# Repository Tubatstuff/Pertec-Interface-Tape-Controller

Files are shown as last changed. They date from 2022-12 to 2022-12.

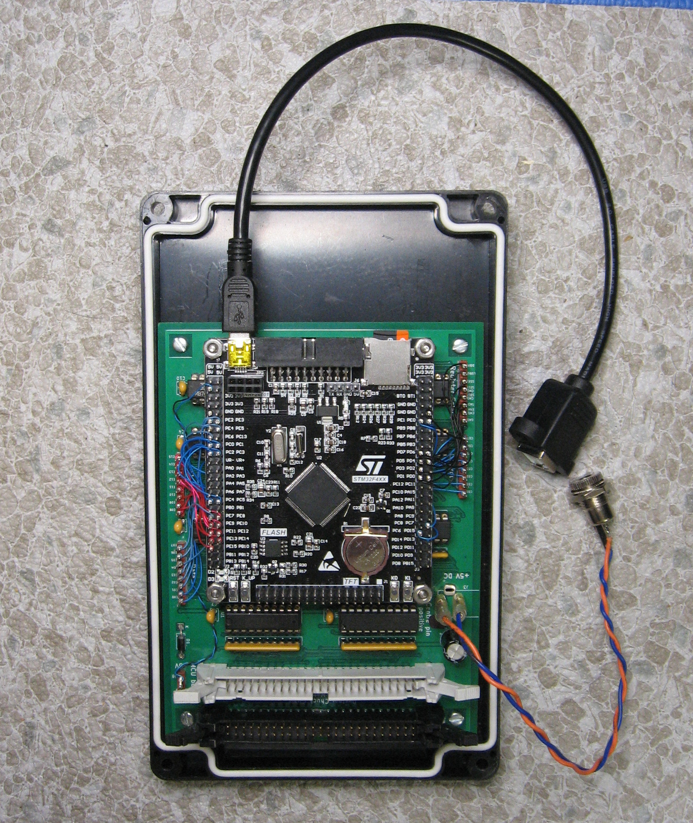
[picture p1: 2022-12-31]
doc/Pertec_Assem.jpg

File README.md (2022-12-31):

This is the repository for a controller to formatted Pertec tape interface.

The directories are as follows:

	doc - Documentation
	firmware - Controller firmware
	kicad - KiCAD schematics, board layout, etc.

The firmware can be built from source using the gcc-arm-none-eabi compiler
and the libopencm3 development library (libopencm3.org) which is covered by
the GNU General Public License v3.0, as is this project.

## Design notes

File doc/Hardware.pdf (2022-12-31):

# Pertec Tape Controller, Version 1.0

January, 2023
Chuck Guzis, Sydex, Inc.

FOREWORD

This document describes the operation of my Pertec tape drive controller. This controller consists of the Pertec bus interface logic and an STM32F4 microcontroller, although any microcontroller of sufficient capabilities can be used.
Frequent reference is made to the Pertec interface description, located in the file 'Pertec 9-Track Tape Interface.pdf'. The library used for the microcontroller program is located at https://libopencm3.org/. The microcontroller data sheets can be found at http://www.st.com.

INTERFACE CONVENTIONS

The Pertec interface is typical for its time; 5 volt TTL, with transmitting done via open-collector logic terminated in 220 ohm to +5, 330 ohm to ground resistor networks. Logic is negative; that is, 0 volts is true, 5 volts is false.
There are about 52 unidirectional signal lines that are distributed over two 50-conductor cables with interleaved ground lines. Depending on vendor implementation, some of these signals may not be used. Others may have vendor-unique interpretations.
Unlike many protocols, the Pertec protocol does not involve handshaking. Data read is transferred from the tape formatter and marked by pulsing a strobe line true--there is no corresponding controller-to-formatter protocol signalling that the data has been accepted. Similarly, when writing, whatever data is present on the controller-to-formatter data lines is transferred to tape and the transfer marked by pulsing a "data written" strobe.
Various other signals may be pulsed during the read or write process; it is up to the controller to "catch" these signals.
Commands to the tape formatter involve data transfer or tape motion without data transfer. For data transfer (i.e. read and write), operations are initiated by the controller pulsing the "IGO" line; that is, bringing the level low for at 2 microseconds. Operation commences on the trailing edge of the pulse and "formatter busy" is asserted. The type of operation is determined by other command lines.
For example, a simple read in the forward direction involves pulsing IGO with no other lines asserted. As each byte is presented to the controller, the IRSTR line is pulsed. A read in the reverse direction involves asserting IREV with IGO.
Writing is initiated by asserting IWRT with IGO. As the formatter acceptseach byte of data from the controller, IWSTR is pulsed. However, see below for the use of ILWD (last word) to signal the end of a block.

All data transfer operations involve the formatter setting IDBY active for the duration of the transfer, after which IFBY is also de-asserted.
Non-data transfer, i.e. tape motion, operations do not set IDBY, but do set IFBY (formatter busy) and do not involve IGO. So, to rewind a tape to load point, IRWD is pulsed, IREW goes active, with IRDY (drive ready) going inactive. When load point is reached, IREW goes inactive and IRDY goes active.
Similarly, if IRWU is pulsed (some implementations require that IREW also be asserted), the tape rewinds and is unloaded and is ready for removal.
Block length is signaled on a read by IDBY going inactive during a read operation. On writing, ILWD must be asserted just before presenting the last byte of data in a block. Generally, ILWD can be asserted immediately after IWSTR goes inactive for the penultimate byte in a block.
Errors are signaled during a transfer; there are two general types. ICER is pulsed for a "corrected" error during reading. IHER is pulsed for a "hard" (uncorrected) error during both read and write operations. IFMK is pulsed during a read when a file mark (tape mark) is encountered.
There are other operations that can be implemented by a given drive/formatter combination; many of these are vendor-unique and are discussed in the documentation for your particular drive.

CONTROLLER IMPLEMENTATION

The controller as implemented here consists of two main parts. The first part is simply TTL level logic to interface to the tape formatter and consists mostly of flip-flops, receivers and random logic. The purpose is to reduce the 52 signal lines down to fewer I/O lines and to catch any pulses emitted by the formatter. The second part is a microcontroller that represents the "brains" of the controller.

INTERFACE LOGIC

Please refer to the schematic for this narrative.

TAPE DRIVE CONNECTORS (Sheet 2)

All signal lines are shown. Only 2 are unconnected; ISGL which, on some drives signals 800 bpi NRZ mode; and IDENT, which indicates that the drive is reading the identification burst information. Neither controls drive operation and either does not appear on many drive implementations.
IFEN is strapped as permanently active. The use of multiple separate formatters on drives shared by multiple hosts is not common on current systems.
All other formatter-to-controller signals are terminated by 220/330 ohmresistor networks RN1, RN2 and RN3.

TAPE CONTROL REGISTERS (Sheet 3)

U10 and U11 are 74ABT574 8 bit latches that are capable of driving 60 ma loads. Other families’ version of this latch may be used, provided that a 40 ma drive capability is ensured. They are connected to 16 control bits on the formatter interface. At startup, they are both tri-stated (high impedance), and enabled by bringing the CMDENA line low from the microcontroller. The upper or lower 8 bits of the 16 output signals are clocked from the microcontroller via the CMDSEL0 and CMDSEL1 lines. Since the latches are in high-impedance mode at startup, they cannot affect drive operation even if they are loaded with random values. As usual, these lines are low-active.
N.B. It is possible to reduce the number of GPIO bits required by connecting the command data lines to the MCU data in/out lines and loading either half of the control registers from the data lines. Logic will be a bit more complicated, however.

TAPE DATA REGISTERS AND DATA CONTROL (Sheet 4)

Data in and out to the formatter is latched by U1 and U2 (74ABT574). Both are connected to the microcontroller which must operate the common lines bidirectionally. The data direction (read or write) is controlled by the DDIR signal from the microcontroller, which tri-state enables one or the other (OE is driven through inverter U3A). In the case of output during a write operation, odd parity is generated by U5, 74LS280. Many drives do not use this signal, but it's provided for completeness.
Read and write strobes (IRSTR and IWSTR) are caught on the trailing edge by flip-flops (74LS74) U4A and U4B. The output of these is incorporated in the status registers (see section 3.1.5, Sheet 6).
Both registers are reset by the microcontroller pulsing TACK low.
Note that the output register U2 must be latched with data before IGO and IWRT are asserted. Thereafter, WDEMTPY is asserted after each byte is accepted by the formatter. Prior to the last byte to be written is latched into U2, ILWD must be asserted.
For reading, RDAVAIL is set when the formatter makes a byte of read data available.

POWER/MICROCONTROLLER INTERFACE (Sheet 5)

Sheet 5 describes the headers dedicated to the microcontroller interface. These are wired to appropriate pins on the microcontroller card.
+5 volts is provided from two sources; the first is the external connection via J3; the second is supplied via the microcontroller card, which is, in turn supplied by the USB interface. Schottky diode D1 prevents external power coming in via J3 from over-driving the USB power.
Bypass capacitors (104) are supplied at every IC.

STATUS REGISTERS (Sheet 6)

Tri-state buffers U6 and U7 furnish status information from the formatter as well as the transient status for file mark, corrected error and hard error, latched by U8 and U9. These 3 status bits ar reset at the trailing edge of the IGO signal, as all three statuses occur during data transfer.
Output from U6 and U7 is selected by the SSEL microcontroller signal. The status bits are arranged such that the status selection need not be changed during the data phase of a read or write
command. U6 and U7 may be any TTL-compatible logic family (e.g. LS, AS, HCT, ACT, etc.) but must not be CMOS (e.g. HC) because the signal levels at the 220/330 termination from the tape drive result in high level signals that are specified as “ambiguous” for 5 volt CMOS. The result could be erratic operation of failure of U6 or U7.

MICROCONTROLLER OPERATION OUTLINE

The code required to run the Pertec interface is straightforward. The basic tasks are as follows:
1. Initialize clocks, GPIO, tape interface, SD card interface and USB communication interface.
2. Poll for next operation to be performed.
3. Perform the operation; go to step 2.

INITIALIZATION

On microcontroller powerup, all GPIO ports should be in input mode with weak pullup enabled. This prevents any undesired activity on the tape drive.

The interface is organized as several 8-bit ports, set up as follows:
1. Data port (J4), bidirectional, initially in input mode.
2. Status port (J5), input mode.
3. Control port (J6), output mode
4. Register select port (J7), output mode
On some microcontrollers, particularly ARM-based ones, GPIO ports are generally 16 bits. Writing a value to an 8 bit half of a 16-bit register is a bit unconventional. One first sets all bits in the 8 bit half to ones, then clears the appropriate bits that are desired to be zeroes.
The register select (J7) port should be first initialized with all high-level bits (ones). This has the effect of disabling the control port output.
Next, the control port (J6) should be written with all ones in both 8 bit halves, using the register select bits (CMDSEL0 and CMDSEL1) set appropriately.

Register select bit TACK should be pulsed to reset the data status bits.

SD card, communications and clock should be set up as appropriate for the choice of microcontroller and software.

TAPE POSITIONING

Tape can be rewound, unloaded, or spaced in the forward direction by first ensuring that the tape drive is online and ready. This is done by polling for the IRDY bit active. If a rewind is attempted, it can be skipped if the ILDP (load point) status is active.
The appropriate command bits are set in the control port using the register select (CMDSEL0 and CMDSEL1) bits. Before setting, the control port output should be disabled (CMDENA bit), the control register loaded, then enabled.
Operation status should be monitored until complete.

TAPE READING

Tape reading operation is similar to the tape positioning protocol, with the difference that IGO is pulsed at the beginning of the operation. Further, TACK should also be pulsed to clear the "read data available" flag. All error flags are reset upon release of IGO. Tape motion ensues, with IFBY being set. When data has been processed by the formatter, IDBY goes active and each byte read setting the RDAVAIL flag in the status register. The data byte can then be read from the data register and stored. The transfer is then acknowledged by pulsing TACK. At the conclusion of the tape block transfer, IDBY is released. On many streaming drives, it is not necessary to wait for IFBY to clear; the next command can be issued immediately. Error flags and file mark indication are available in status register.
Most tape formatters read an entire block, process it, then transfer it to the host. As a consequence, transfers occur in bursts, with idle time between. This should leave more than enough time to write the block to the SD card; in our implementation on the STM32F407, the data write to SD is initiated using DMA transfer, such that SD writing can overlap with tape reading.

TAPE WRITING

Tape writing is initiated in a manner similar to tape reading, with several important differences. The data register is set to output mode; output data is latched into the data register before the write operation is initiated. Upon data being transferred to the tape drive, the WDEMPTY bit is set in the status register and the next data byte should be latched into the data register. Before the last byte of a block is written, the ILWD bit should be set in the control register. This can be done as soon as the WDEMPTY bit is set for the preceding byte. Note that the IFPT (file protect) bit will be set in the status register if the tape has not been write-enabled (no "ring").
Tape marks are written by asserting IWRT and IWFM as well as IGO. This will result in a single file mark being written. The IEOT status should be tested before each block write to avoid writing past end-of-tape.

MISCELLANEOUS NOTES

A few implementation-specific details should be noted here.

The FAT32 file system implemented on the SD card, is realized using Elm Chan's FATFS. Single file size is limited to 2GB, which should not be a problem, even at 6250 GCR density.
Our implementation time- and date-stamps each file as it is created. This is done by virtue of the microprocessor card used containing a clock backup battery.
By default, tape image files are recorded in SIMH TAP format.

The source code contains provisions for host interface via USB CDC ACM or, alternatively, serial asynchronous I/O at 115200 bps. The selection is done by specifying a compile-time option. Transfer from SD card to host can be done in two ways. The SD card can be removed and inserted into a suitable SD reader on the host system. As an alternative, YMODEM 1K transfer is implemented. Many terminal programs, such as Linux minicom support this protocol.
A few ICs, the 74LS04 and 74LS74 ICs have unused, unterminated inputs. These should be tied to +5 or 0 volts if CMOS HCT logic is used. On the current version of the PCB, this should be done manually; currently, they are left open for the possibility of future modification.

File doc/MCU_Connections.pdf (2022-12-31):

# Connections Between PTCB and STM32F4VExx MCU Module

## January, 2023

C. P. Guzis, Sydex, Inc.

As described in the “Hardware” document, the prototype Pertec Tape Controller board was implemented using the STM32F4VEXX development board described here: https://stm32-base.org/boards/STM32F407VET6-STM32-F4VE-V2.0.html.
The connections from the controller board to the MCU were made using wire-wrap techniques, but a cable using Dupont connectors should probably be the preferred method. Another possibility is to construct a “mezzanine” printed circuit board that plugs into the controller board and mates with the microcontroller development board of choice.
In any case, the software supplied with the board uses the following pin assignments. In all cases, the first reference is to the controller board pin, the second is the microcontroller connection:
J8:
+5 → any 5V
GND → any GND
Data:
E00 → PE0 E02 → PE2 E04 → PE4 E06 → PE6 E01 → PE1 E03 → PE3 E05 → PE5 E07 → PE7 Status:
E08 → PE8 E10 → PE10 E12 → PE12 E14 → PE14 E09 → PE9 E11 → PE11 E13 → PE13 E15 → PE15 Control:
C00 → PC0 C02 → PC2 C04 → PC4 C06 → PC6 C01 → PC1 C03 → PC3 C05 → PC5 C07 → PC7
Register Select:
CMD ENA → PD1 DDIR → PD5 | LDBUF → PD4 | SSEL → PD3
CMD SEL0 → PD7 CMD SEL1 → PD6 TACK → PD0 | GND → any GND

Note that it’s possible to change any of these association by editing the gpiodef.h file. All other uses of the pin names in the software are symbolically referenced.

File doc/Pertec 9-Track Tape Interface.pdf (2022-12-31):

# Pertec 9-Track Tape Interface

## Electrical

The interface uses two 50 conductor (ribbon) cables, P1 and P2. All odd-numbered conductors are grounded, with the exception of conductors 1 and 3 on P2.

All signal levels are TTL (5 volt). Drivers are open-collector and must be capable of sinking 36 mA. The last device on each end of any cable should be terminated on all receive lines with 220 ohms to +5 volts and 330 ohms to ground. (Note: I suspect that 220 ohm to 1K ohm to +5 will suffice on short (less than 1 meter cable runs.)

All signals are active-low.

## Signal Definitions

In the following, the source (driver) of the signal is signified by either Drive for the tape drive or Host for the host (controller). Note also, that the bit ordering is IBM-style. That is, bit 0 is the most significant bit in a byte and bit 7 is the least significant bit position. Don't let this trip you up!

P1 Connections

P1 Pin | Signal Name | Asserted by | Description
2 | IFBY | Drive | Forrmatter busy—Set by trailing edge of IGO, clears when command finished (but you can send a new command as soon as IDBY clears)
4 | ILWD | Host | Last word—Used to tell drive that this is the last word (byte) to be written in this record, Must be asserted at least 300 nsec. before trailing edge of final IWSTR pulse.
6 | IW4 | Host | Write data bit 4
8 | IGO | Host | Initiate command—Pulsed low for at least 1µsec. to start command execution. The formatter address lines must be stable throughout the pulse and until IFBY drops.
10 | IW0 | Host | Write data bit 0 (MSB!)
12 | IW1 | Host | Write data bit 1
14 | ISGL | Drive | Selected drive fault on some drives; NC on others. If used, it is cleared by de-asserting, then re-asserting IFEN.
16 | ILOL | Host | Load on-line—Pulsing this line at least 1µsec. begins the tape load sequence on many drives.
18 | IREV | Host | Reverse—When asserted, indicates operation is to be performed in the reverse direction.
20 | IREW | Host | Rewind—A pulse of at least 1 µn;sec. starts the tape rewind sequence. Completion is signalled by IRWD going inactive and IRDY being asserted by the drive.

22 | IWP | Host | Write parity. This is (almost always) odd parity computed over IW0–IW7 and on some drives is ignored and computed by the formatter.
24 | IW7 | Host | Write data bit 7 (LSB!)
26 | IW3 | Host | Write data bit 3
28 | IW6 | Host | Write data bit 6
30 | IW2 | Host | Write data bit 2
32 | IW5 | Host | Write data bit 5
34 | IWRT | Host | Write—When asserted with IGO begins a write sequence.
36 | IRTH2 | Host | Write density select 2—On some drives, this signal, along with IRTH1 is used to select the drive write density. If it is implemented, it is valid only at BOT and must be asserted with IGO during the first write sequence.
38 | IEDIT | Host | Edit—Not implmented on all drives. See notes in the next section for details on its application.
40 | IERASE | Host | Erase—When asserted with IWRT and IGO, causes tape to be erased, usually for a predetermined length. Usually used to recover from write errors or provide extra space for mode changes (i.e. Read after write).
42 | IWFM | Host | Write filemark&mash;When asserted with IWRT, writes a filemark.
44 | IRTH1 | Host | Write density control—See IRTH2, pin 36.
46 | ITAD0 | Host | Transport address bit 0 (MSB!)—Used to address multiple drives on a single controller.
48 | IR2 | Drive | Read data bit 2
50 | IR3 | Drive | Read data bit 3
All odd | Gnd | – | Signal ground.

P2 Connections

P2 Pin | Signal Name | Asserted by | Description
1 | IRP | Drive | Read data parity (odd) This is not a ground pin!
2 | IR0 | Drive | Read data bit 0 (MSB!)
3 | IR1 | Drive | Read data bit 1 This is not a ground pin!
4 | ILDP | Drive | Load point—Asserted whenever the tape is at the load point (or might as well be, as far as the controller needs to know -- there may be hidden repositioning)
6 | IR4 | Drive | Read data bit 4

8 | IR7 | Drive | Read data bit 7 (LSB!)
10 | IR6 | Drive | Read data bit 6
12 | IHER | Drive | Hard error—Pulsed during IDBY when a hard data error (or illegal character in the IRG) is seen. Note that most modern formatters correct this error automatically.
14 | IFMK | Drive | File mark—Pulsed during IDBY when a tape mark is seen. Note that you have to catch this as it goes by!
16 | IDENT | Drive | Identification—Asserted while drive is actually reading the PE ID burst, dropped the rest of the time so it's up to the controller to catch it and remember.
18 | IFEN | Host | Formatter enable—This signal should normally be asserted all the time. If dropped for a minimum of 2 µsec., aborts any comman that asserts IDBY (I/O, skip, but not rewind or unload).
20 | IR5 | Drive | Read data bit 5
22 | IEOT | Drive | End of tape—Asserted whenever the tape is past the EOT marker, clears when the tape is backspaced past it.
24 | IRWU | Host | Rewind and unload—A pulse of at least 1 µsec. initiates a rewind-with-unload and sets drive off-line. Some drives require that IREW is also asserted.
26 | INRZ | Drive | NRZI mode—Signals 800 BPI mode on some drives.
28 | IRDY | Drive | Ready—Signals that tape is fully loaded, on-line and not rewinding. This must be asserted by the drive before it will accept any command.
30 | IRWD | Drive | Rewinding—This is asserted by the drive while the tape is rewinding.
32 | IFPT | Drive | File protect—This signal is asserted continuously when the tape is not write-enabled (i.e. no ring present).
34 | IRSTR | Drive | Read strobe—Pulses low for at least 200 nsec. when data on IR0-IR7 and IRP are stable before leading edge; typically held for 200 nsec., but this is not a requirement. Note that data is made available–there is no check made to ensure that the host has picked it up.
36 | IWSTR | Drive | Write strobe—Pulses low for at least 200 nsec. when the drive is ready to accept data. This is roughly similar to an "Acknowledge" signal after data has been received. The next data byte can be presented immediately.
38 | IDBY | Drive | Data busy—This signal is asserted during I/O phase of read or write commands. It generally lags a few milliseconds after the drive asserts IFBY.
40 | ISPEED | Drive | High-speed—This signal is asserted when commands are executing in high-speed mode; that is, when the drive is not operating in start-stop mode.
42 | ICER | Drive | Corrected error—This signal is pulsed during IDBY when a single-track dropout is successfully corrected using the parity information.

44 | IONL | Drive | Online—Asserted when the drive is online; clears within 1 µsec. of being taken offline.
46 | ITAD1 | Host | Transport address bit 1 (LSB!)
48 | IFAD | Host | Formatter address
50 | IHISP | Host | High speed select—When asserted 1 µsec. before and then with IGO (de-asserted any time after the trailing edge of IGO selects high-speed (streaming) mode.
5-49 odd | Gnd | – | Signal ground.

## Usage

Commands are started by setting up the IREV, IWRT, IWFM, IEDIT, and IERASE signals and then pulsing IGO. Various combinations of these signals are possible to get vendor-specific commands.

The basic ones are:

Read

Assert IGO. The drive reads data and presents data at IR0–IR7, strobing each byte with IRSTR. No check is made for data received by the host; it's simply shoveled out by the drive until the end-of-block or error. ICER and IHER signal soft and hard errors, respectively and IFMK will indicate a filemark. Observe that these signals are just pulses that accompany each data byte—they do not latch.

Read Reverse

Assert IGO while asserting IREV. Operates the same as a forward read, but data is presented in reverse order.

Write

Assert IWRT while asserting IGO. As the formatter accepts each byte of data, it signals with the IWSTR strobe. Again, no check is made to see if the data presented at IW0-IW7 and IWP is valid--the host must present data and parity prior to the assertion by the drive of IWSTR. When the last byte in a block is presented for writing, the host must assert ILWD.

Write Filemark

Assert IWRT and IWFM while asserting IGO. One filemark will be written.

Erase

Assert IWRT, IWFM and IERASE while asserting IGO. This command erases a few inches of tape, usually as part of a write error recovery sequence.

Skip Block Forward

Assert IERASE with IGO. This functions similarly to a read but with no data transfer.

Skip Block Reverse

Assert IERASE and IREV with IGO. This is similar to a read reverse operation, but with no data transfer.

Search Filemark Forward

Assert IWFM and IERASE with IGO. This causes the drive to skip forward to the next filemark or EOT. The tape is left positioned after the filemark

Search Filemark Reverse

Assert IWFM, IREV and IERASE with IGO. This causes the drive to skip backward to the preceding filemark or BOT. The tape is left positioned before the filemark

Miscellany

On some drives, IEDIT modifies reverse reads and forward writes so that a record can be replaced. Asserting IEDIT while doing a reverse read causes the drive to move further back into the IRG preceding the record being spaced over. Asserting IEDIT while writing tells the drive to modify the write current turn-off to avoid a glitch.

Streamers have a drive-dependent "reinstruct time" which is the size of the time window after completion of a command during which you can issue a new command without the drive having to reposition. If you fail to make this window, then the drive stops and backspaces a few records to get a running start at the next record. This can waste a lot of time and movement. Asserting IHISP needlessly will probably result in operations taking longer if succeeding operations cannot be issued in time, so care must be used in attempting to use the "high speed" mode of operation.

As regards transfer speeds, a good rule of thumb is that an interface should be designed to provide or receive data at least at 1MB/second. Observe that there's no handshaking for data transfers, so it's incumbent on the controller to satisfy all timing requirements.

Glossary

Here are a few terms used in this discussion:

BOT or "beginning of tape". This is not the physical start of a tape, but rather the point after the beginning where a reflective foil tape marker has been applied. All tape before this is classified as "leader".

EOT or "end of tape". This is not the physical end of the tape, but rather a point somewhere before the physical end where a reflective foil marker has been placed. As a rule of thumb, it's safe to write at least one short record past the EOT marker.

Filemark is a reserved bit pattern used to delimit files on a tape. Most drives can scan a tape in either forward or reverse directions at high speed to locate a filemark. Some system software uses two or three consecutive filemarks to provide extra levels of delineation.

Write enable or "write ring" is a plastic ring that fits into a groove in the back of a reel of tape to tell the drive that it's safe to write to the tape. "No ring, no write" is an old data processing rule.

Formatter is a intermediate interface between the drive and the controller that provides buffering and error correction facilities for a drive or group of drives. One formatter can service several drives. It's also possible to interface a drive to more than one formatter.

Parity is used for error control on tape drives. One bit in a nine-bit frame is reserved for parity and some tape formats also append a longitudinal parity frame at the end of a block, so that single errors can be corrected. In 9-track tapes, the number of bits in a frame must be odd. Some 7 track tape formats allowed for even parity as long as no all-zero frames are written.

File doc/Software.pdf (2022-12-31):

# A Guide to the Pertec Tape Controller Software

## January, 2023

Chuck Guzis, Sydex Inc.

## Introduction

This document serves as a guide to implementing microcontroller (“MCU”) firmware for the Pertec Tape Controller board (“PTCB”). This should not be construed as a strict set of rules, but merely guidelines, should a different microcontroller or firmware be desired.

As written, the firmware supplied was targeted at a specific MCU board, the STM32F4xx development board employing an ST Micro STM32F407 microprocessor. It was selected primarily because it was inexpensive, had more than adequate speed and memory and 5 volt tolerant GPIO, support for SD cards and full-speed USB OTG. It also has provisions for an Ethernet MAC and other features not used. A battery-backed real-time clock/calendar was a plus for time-stamping files.

Since the PTCB employs TTL-level logic, an MCU with 5 volt tolerant I/O is important, unless the implementer desires to add external level-shifting logic. It should be noted that the MCU is not directly connected to any of the tape interface pins, so drive/current sinking requirements are minimal.

As designed, the software allows for use of either asynchronous serial (UART) or USB (CDC ACM) interfaces, the choice being determined at compilation time.

## Requirements

An essential understanding of the interface to the PTCB logic is important when selecting an MCU. Note should be taken of the following:

There are 4 8-bit GPIO interfaces on board:

One 8 bit bidirectional interface for data.

One 8 bit output interface for drive control.

One 8 bit input interface for status.

One 8 bit output interface for logic control.

Data interfaces employ latches to hold data going to and from the drive. The drive formatter itself has no handshake provisions; it signals when a byte is available for reading and when it has accepted a byte for writing. Flip-flops record the state of both types of traffic and can be interrogated in the status register.
Some signals are transient during a data transfer, such as hard error status; they too, are made available in the status register.

Since an 8 bit interface to all registers is used, the logic control lines signal which latch is being addressed by the MCU. For example, there are 16 status signals, divided into two groups of 8 bits; the first are signals that should be interrogated during a data transfer; the second are static signals that can be checked after a transfer has been concluded.

If GPIO is at a premium, it should be possible to make use of only three 8-bit GPIO interfaces, with the drive control sharing the data interface. This has not be tried, but there appears to be no impediment toward using the interface in this way.

The logic control interface determines which 8 bit status register is selected for reading by the MCU, which 8 bit drive control register is selected, and the state of the data registers (empty or full). Additionally, a signal is provided to force the drive control registers into a high-impedance state.

For a call-out of the various tape interface signals, see the interface description in the PTCB hardware description document.

Status Registers
The status registers are configured thus; note that the status as read is negative logic (0 level = true):

Status register 0:

xxxx xxx1 = Read data parity bit; not used by most drives, which enforce odd parity.

xxxx xx1x = Data busy; corresponds to the IDBY interface signal.

xxxx x1xx = High speed mode; corresponds to the IHSP interface signal, used on streaming drives.

xxxx 1xxx = Read data available; signals that data has been latched; cleared by asserting TACK.

xxx1 xxxx = Write data buffer empty; signals that the drive has accepted data; cleared by TACK.

xx1x xxxx = File mark detected; cleared by asserting the GO control signal.

x1xx xxxx = Hard (uncorrectable) error detected; cleared by GO assertion.

1xxx xxxx = Corrected error detected; cleared by GO assertion.

Status register 1:

xxxx xxx1 = IRNZ; used by some drives to signal 800 bpi mode.

xxxx xx1x = End of tape detected; corresponds to IEOT on the tape interface.

xxxx x1xx = Drive is online; corresponds to IONL on the tape interface.

xxxx 1xxx = File protect; corresponds to IFPT on the tape interface.

xxx1 xxxx = Tape is rewinding; corresponds to IRWD on the tape interface.

xx1x xxxx = Tape is at load point (beginning); corresponds to ILDP on the tape interface.

x1xx xxxx = Drive is loaded and ready; corresponds to IRDY on the tape interface.

1xxx xxxx = Formatter busy; corresponds to IFBY on the tape interface.

Command Registers
The two command registers are negative-logic and configured thus:

Command register 0:

xxxx xxx1 = “GO” – when asserted, initiates data activity on trailing edge Also resets error status.

xxxx xx1x = Last word. Used during writes, must be asserted before the last byte is transferred

xxxx x1xx = Load; on some drives, pulsing this line initiates a tape load sequence

xxxx 1xxx = Reverse – when asserted with some operations causes reverse tape movement xxx1 xxxx = Rewind; when asserted, causes tape to rewind to load point

xx1x xxxx = Write; signifies a write operation

x1xx xxxx = Read threshold 1 – IRTH1 on the Pertec bus, use varies by manufacturer

1xxx xxxx = Read threshold 2 – IRTH2 on the Pertec bus, use varies by manufacturer

Command register 1:

xxxx xxx1 = Write file mark; when asserted with Write, causes a tape mark to be written.

xxxx xx1x = Erase, when asserted with Write, causes a long block gap to be written. Can be used with other bits for non-write operations.

xxxx x1xx = Edit mode – used with other commands for various operations.

xxxx 1xxx = Rewind and unload – unloads tape and brings drive offline.

xxx1 xxxx = Initiate high-speed operation. May not be implemented on some drives.

xx1x xxxx = Drive address bit 1.

x1xx xxxx = Drive address bit 0.

1xxx xxxx = Formatter address; some drives combine this with the drive address to form a 3 bit drive select address.

It’s important to note that the meaning of various command bit combinations can vary between drive models and manufacturers. The OEM manual for the drive should be considered to be the final authority on this.

Finally, there is an 8 bit logic control register configured as follows (so labeled on the PCB):

ENA = Command enable. A low level on this line enables the command register output. A high level puts the command register output into high-impedance mode.

DDIR = Data direction. A high level means that the MCU is in input mode and is ready to accept data from the read data register. A low level means that the MCU is prepared to send data to the write data register, strobed by a transition on LBUF (see below). Note that it is essential that the MCU data register direction be set accordingly.

LBUF = Load buffer. A low-to-high transition loads the write data register from the MCU data output.

SSEL = Status select. Selects between status register 0 and status register 1.

CSEL0 = Command select 0. A transition on this line loads command register 0 from the MCU.

CSEL1 = Command select 1. A transition on this line loads command register 1 from the MCU.

TACK = Transfer acknowledge. Pulsing this line resets both the ‘Read Data Available’ and ‘Write Data Empty’ status lines.

### Operation Examples

Here follow some general illustrations of common functions.

1. Rewind tape – First check that the drive is online and not at load point (that is, not already rewound). Pulse the “Rewind” bit in the command register. When the bit is reset (high), the tape drive begins rewinding and sets “rewinding” in the status register. Rewind is complete when the “rewinding” status is inactive and the drive reports online and load point.
2. Unload tape – Check if the drive is online, then pulse the “Unload” bit in the command register. When complete, the drive will become offline.
3. Read block – Check that the drive is online, Make sure that the MCU data register is set for input mode. Pulse the “Go” bit in the command register. Test and wait for “Formatter busy”, then wait for “Data busy”. When a data byte becomes available, the “Read Data Available” status register becomes active. Input and store the data byte in memory. Acknowledge the transfer by pulsing TACK in the logic control register. Continue the operation until “Data busy” goes inactive. Check the status register for “File Mark Detected” (the data count will be 0) as well as for “Hard Error” and “Corrected Error” status.
4. Write block – Check that the drive is online and that the “Protected” bit is inactive in the status register. Make sure that the MCU data register is set for output and set the DDIR logic control bit for output. “Prime” the data output register with the first byte of data pulsing “LBUF” and then assert “Go” and “Write” in the command register. Upon releasing “Go”, “Formatter busy” will go active; then “Data busy” will become active. When the drive has accepted the pre-loaded data byte, the “Write data buffer empty” will go active. The “TACK” flag should be reset and the next byte to be written should be loaded (“LBUF”) and the operation should be continued until the next-to-last data byte has been accepted by the drive. Assert “Last word” in the command register, then load the last data byte into the data output register (LBUF). After the drive has accepted the final data byte, “Data busy” will become inactive and the operation status can be examined.
5. Write file name – No data is transferred, but otherwise the operation is similar to “Write block” described above. The difference is that the “Write file mark” bit in the command register is set along with “Write” and “Go”. The operation will be complete when “Data busy” goes inactive in the status register.

### A Practical Implementation

A sample MCU program for the STM32F407 accompanies this design. It is constructed using the gcc-arm-none-eabi C compiler and the libopencm3 ARM-cortex development suite. Firmware programming was accomplished by an ST-Link USB programming tool and the openocd programming software. Debian Linux was used as the host platform, but most 32- and 64-bit Linux or Windows installations should be adaptable. The project software is compiled and linked using a “make” script in a standard “Makefile”. Tape files are created and read in the SIMH .tap file format described at http://simh.trailing-edge.com/docs/simh_magtape.pdf.

What follows is a hierarchical description of the various sets of routines in the sample.

First level Execution begins in the main.c routine. It sets up the various devices and interfaces, namely:

1. Peripheral clocks and GPIO. Initial states of the various GPIO interface pins is established with regards to input vs. output, initial states, etc. This occurs in the miscsubs.c module.
2. If USB serial interface is being used the usbcdc.c routines are called to initialize connection with the host; if UART serial interface is compiled, the uart.c routines are called to establish the bit rate (normally 115,200).

3. The system “tick” clock is set up in miscsubs.c to provide an interrupt approximately every millisecond. After every 1024 milliseconds, an LED is toggled alternately on an off to provide a visual “I’m alive” indication. This millisecond counter is also used as a deadman timer in serveral routines, such as the ymodem interface.
4. A free-running timer counter is set up with a period of 500 nanoseconds. This is used to provide precise delays in establishing pulse widths for example. This timer is initialized in miscsubs.c also.
5. The operator input, wether UART or USB is polled for a “g” character to start operation.
6. The real-time clock is initialized, if necessary to reflect the current time of day and date and is implemented in rtcsubs.c. The MCU development board used in this example has a battery-backed RTC, so it should need to be initialized only when the time of day or date needs to be changed or when a new backup battery is installed. The RTC is used to date files and directories that are created.
7. The SDIO interface in sdiosubs.c is initialized and an attempt is made to mount any SD card that may be present. If none is inserted, it may be mounted manually later.
8. The tape drive interface is initialized to a known state by calling a routine in tapedriver.c. The drive itself may or may not be powered on or online at this point.
9. Control is passed to the command-line processor in cli.c and does not return.

The command-line processor is very simple—it accepts user input, tokenizes the input and calls the routine corresponding to the first token on the input line. The relevant routine is passed the list of the remaining tokens and, after processing the request, returns to the command processor loop. Part of the command prompt is a quick summary of tape drive status by calling a routine in tapeutil.c.

Second Level routines are invoked by the command processor. Some are very simple, such as the command help routine, which either displays a list commands or a brief description of a single command (given as an argument). Others deal with file system operations (located in filesub.c), tape operations (located in tapeutil.c), Ymodem file transmit/receive (located in ymodem.c) or real-time clock setting (located in rtcsubs.c).

Third Level routines are not directly invoked by the command processor, but service various requests from the second-level code. So, for example, while the code in tapeutil.c processes user requests for tape activities, it performs no direct operations on the tape interface. Rather, it calls various routines in tapedriver.c, which contains all of the lowest-level tape code. These third-level routines are as follows:

1. comm.c contains higher-level serial I/O code to perform formatted input or output, such as Uprintf which is a simplified printf clone. Depending on whether USB or UART communication is desired, the appropriate lower-level handler is called (either usbcdc.c or uart.c).
2. ff.c is the FATfs code developed by ChaN. It implements the basic filesystem for FAT, FAT32 and exFAT and can be obtained from elm-chan.org. It requires only a simple sector-level interface found in diskio.c for operation. Long filename support is provided by the ffunicode.c module. Diskio.c in turn, invokes the code in sdiosubs.c.
3. sdiosubs.c contains the driver code for accessing the microSD card contained on the MCU board. It employs 4-line SDIO and DMA to provide I/O activities that can overlap tape operations.
4. filesub.c contains mount, directory and basic I/O services; it interfaces to ff.c.

### 5. tapedriver.c implements low-level tape drive functions, among which are read or write

block, writing file mark, rewind, unload, skip forward or reverse files or blocks, and obtaining drive status.

UART operation can be selected by compiling the MCU code with the symbol USE_UART defined.

A debugging facility may optionally incorporated by defining the symbol SERIAL_DEBUG. It provides simple I/O primitives (e.g. DBgets(), DBprintf()…) through serial UART1. It should not be used also with the USE_UART symbol defined, as both use the same device.

### Thoughts for later implementation

Although the ymodem interface works well for file transfer, it does not operate at the full speed of the USB 2.0 interface. It might make more sense to add a composite USB driver facility implementing a mass-storage device (USB MSD) along with the USB CDC ACM device. Of course, this facility would not be implemented if the UART serial interface was selected.

An EBCDIC display option might be added to the dump command.

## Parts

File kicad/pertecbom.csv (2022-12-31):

Id | Designator | Package | Quantity | Designation | Supplier and ref
1 | C4,C8,C10,C9,C5,C12,C7,C2,C3,C6,C11 | C_Rect_L4.0mm_W2.5mm_P2.50mm | 11 | 104
2 | J1,J2 | PinHeader_2x25_P2.54mm_Vertical | 2 | Conn_02x25_Odd_Even
3 | J3 | BarrelJack_Horizontal | 1 | +5 VDC
4 | J5 | PinHeader_1x08_P2.54mm_Vertical | 1 | Status 0:7
5 | J6 | PinHeader_1x08_P2.54mm_Vertical | 1 | Control
6 | J7 | PinHeader_1x08_P2.54mm_Vertical | 1 | Register Select
7 | RN2,RN1,RN3 | R_Array_SIP10 | 3 | 220/330
8 | U2,U11,U1,U10 | DIP-20_W7.62mm | 4 | 74LS574
9 | U8,U4,U9 | DIP-14_W7.62mm | 3 | 74LS74
10 | U7,U6 | DIP-20_W7.62mm_Socket | 2 | 74LS541
11 | C1 | CP_Radial_D8.0mm_P2.50mm | 1 | 470/16
12 | U3 | DIP-14_W7.62mm | 1 | 74LS04
13 | U5 | DIP-14_W7.62mm | 1 | 74LS280
14 | J4 | PinHeader_1x08_P2.54mm_Vertical | 1 | Data 0:7
15 | D1 | D_DO-41_SOD81_P10.16mm_Horizontal | 1 | 1N5817
16 | J8 | PinHeader_1x02_P2.54mm_Vertical | 1 | MCU Power

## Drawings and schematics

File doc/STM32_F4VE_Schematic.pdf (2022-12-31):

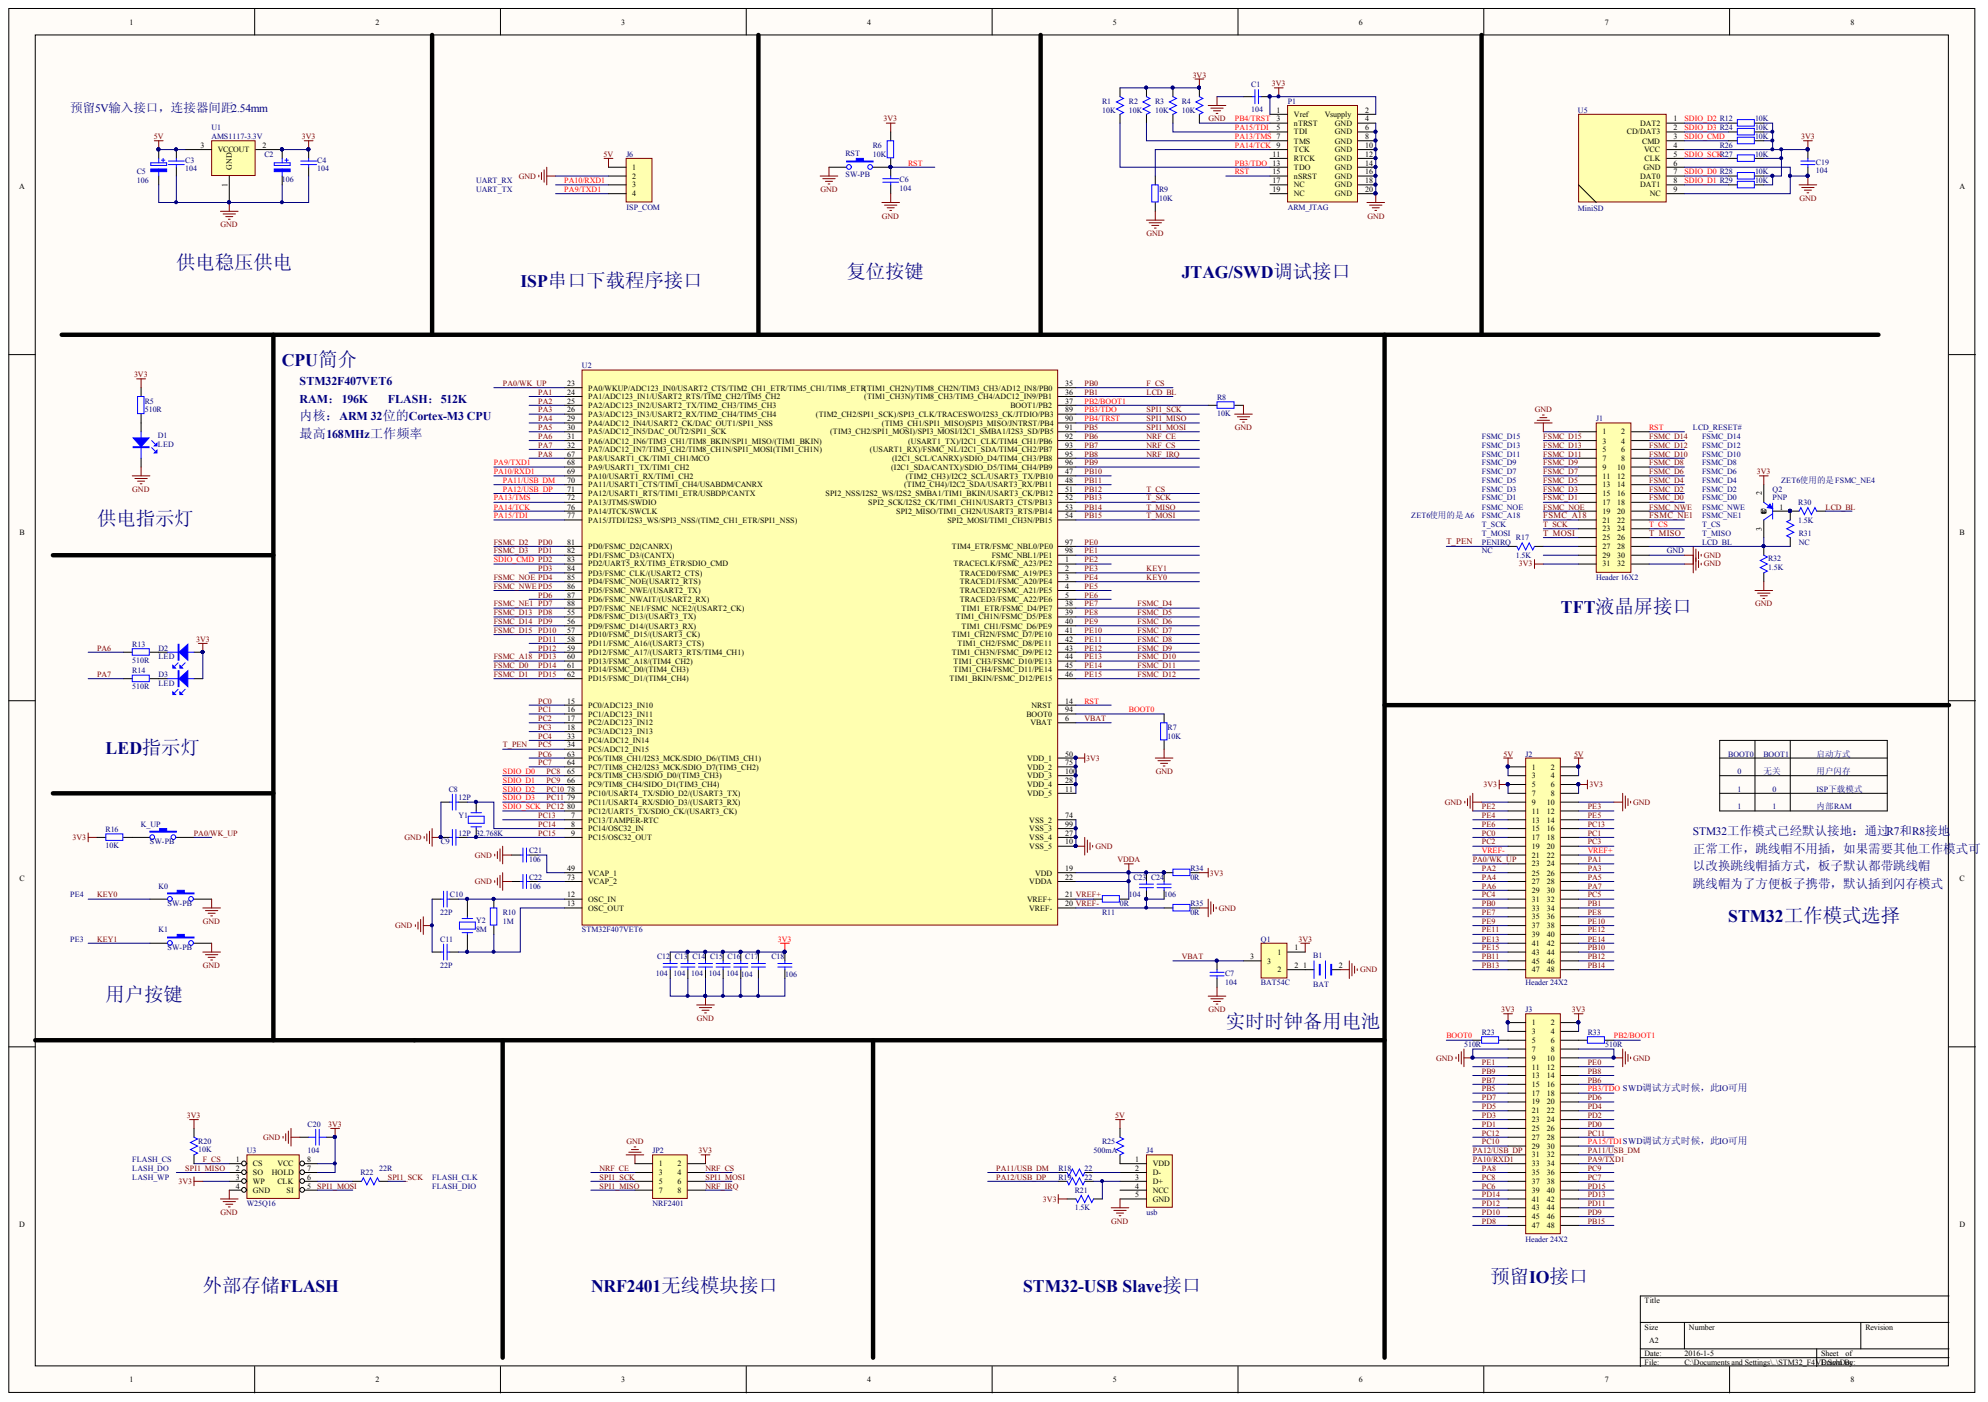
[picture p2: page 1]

SDIO_SCK PC12 | PC12/UART5_TX/SDIO_CK/(USART3_CK) 80

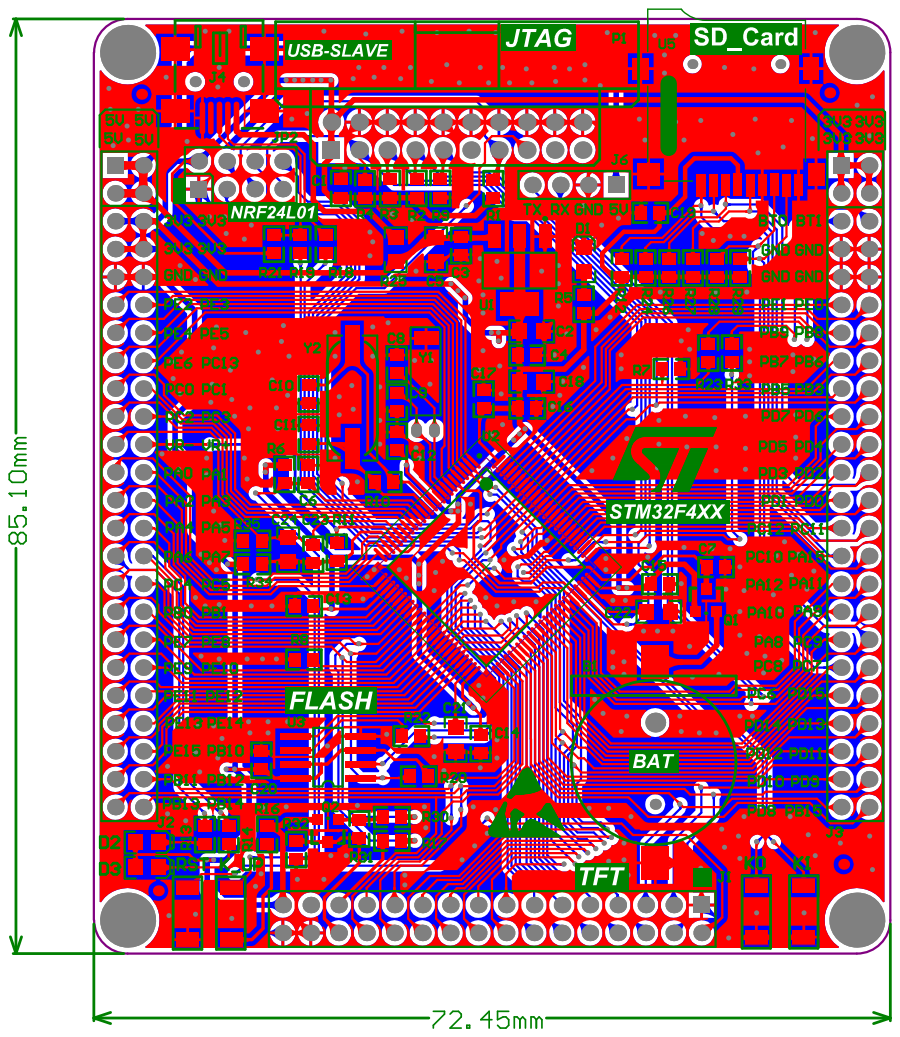
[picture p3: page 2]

Comment | Description | Designator | Footprint | LibRef | Quantity
BAT | | B1 | BAT | BATTERY | 1
104 | Capacitor, Capacitor, Capacitor, Capacitor, Capacitor, Capacitor, Capacitor, Capacitor, Capacitor, Capacitor, Capacitor, Capacitor (Semiconductor SIM Model), [NoValue], Capacitor | C1, C3, C4, C6, C7, C12, C13, C14, C15, C16, C17, C19, C20, C23 | RC0603 | Cap, CAP, CAP, CAP, Cap, Cap, Cap, Cap, Cap, Cap, Cap, Cap Semi, CAP, Cap | 14
106 | [NoValue], [NoValue], Capacitor, Capacitor, Capacitor, Capacitor | C2, C5, C18, C21, C22, C24 | RC0805 | ELECTRO2, ELECTRO2, Cap, Cap, Cap, Cap | 6
12P | | C8, C9 | RC0603 | CAP | 2
22P | Capacitor | C10, C11 | RC0603 | CAP | 2
LED | | D1, D2, D3 | LED0805 | LED | 3
Header 16X2 | Header, 16-Pin, Dual row | J1 | IDE2X16 | Header 16X2 | 1
Header 24X2 | Header, 24-Pin, Dual row | J2, J3 | IDE2X24 | Header 24X2 | 2
usb | | J4 | Mini_USB | usb | 1
ISP_COM | Header, 4-Pin | J6 | HDR1X4 | Header 4 | 1
NRF2401 | Header, 4-Pin, Dual row | JP2 | IDE2X4 | Header 4X2 | 1
SW-PB | | K0, K1, K_UP, RST | SW-SPST | SW-PB | 4
ARM_JTAG | JTAG | P1 | JTAG-20P | JTAG | 1
BAT54C | | Q1 | SOT-23-BAT54C | BAT54C | 1
PNP | PNP Bipolar Transistor | Q2 | PNP_SOT23 | PNP | 1
10K | [NoValue], [NoValue], [NoValue], [NoValue], Resistor, Resistor, Resistor, Resistor, Resistor, Resistor, [NoValue], Resistor, Resistor, Resistor, Resistor, Resistor | R1, R2, R3, R4, R6, R7, R8, R9, R12, R16, R20, R24, R26, R27, R28, R29 | RC0603 | RES, RES, RES, RES, Res2, Res2, Res2, Res2, Res2, Res2, RES, Res2, Res2, Res2, Res2, Res2 | 16
510R | Resistor | R5, R13, R14, R23, R33 | RC0603 | Res2 | 5
1M | Resistor | R10 | RC0603 | Res2 | 1
0R | Resistor | R11, R34, R35 | RC0603 | Res2 | 3
1.5K | | R17, R21, R30, R32 | RC0603 | RES | 4
22 | | R18, R19 | RC0603 | RES | 2
22R | | R22 | RC0603 | RES | 1
500mA | | R25 | RC0805 | RES | 1
NC | | R31 | RC0603 | RES | 1
AMS1117-3.3V | | U1 | SOT-223 | 11 | 1
STM32F407VET6 | | U2 | | STM32F407VET6 | 1
W25Q16 | | U3 | SOP8L | W25X16 | 1
MiniSD | | U5 | TF_SD | MiniSD | 1
32.768K | 晶振 | Y1 | JZ32768 | CRYSTAL | 1
8M | Crystal | Y2 | 49S_SMD | CRYSTAL | 1

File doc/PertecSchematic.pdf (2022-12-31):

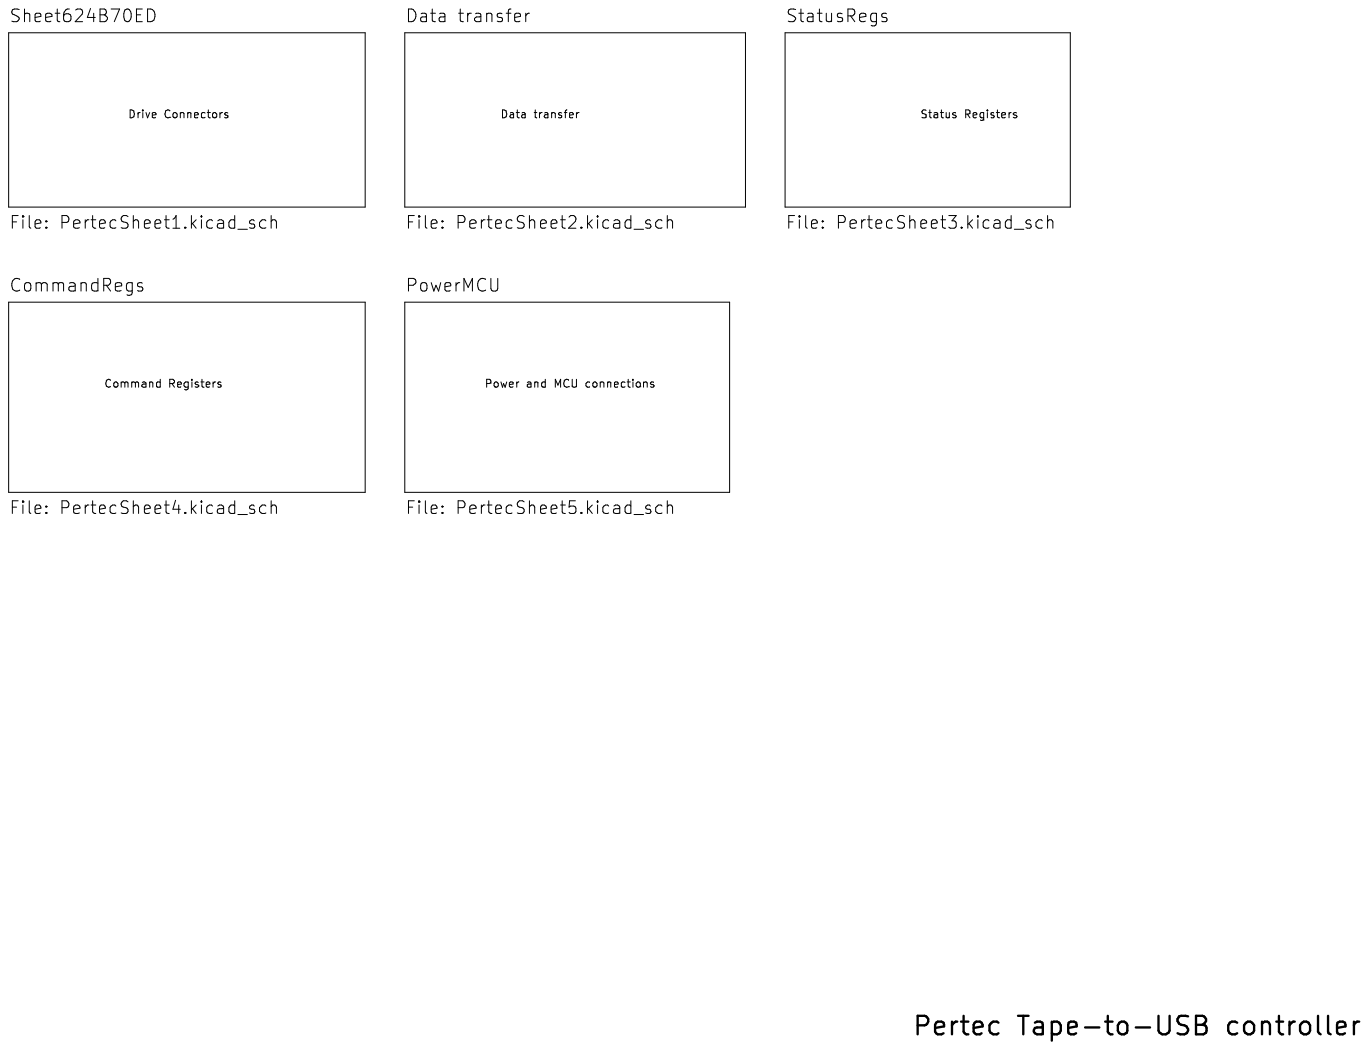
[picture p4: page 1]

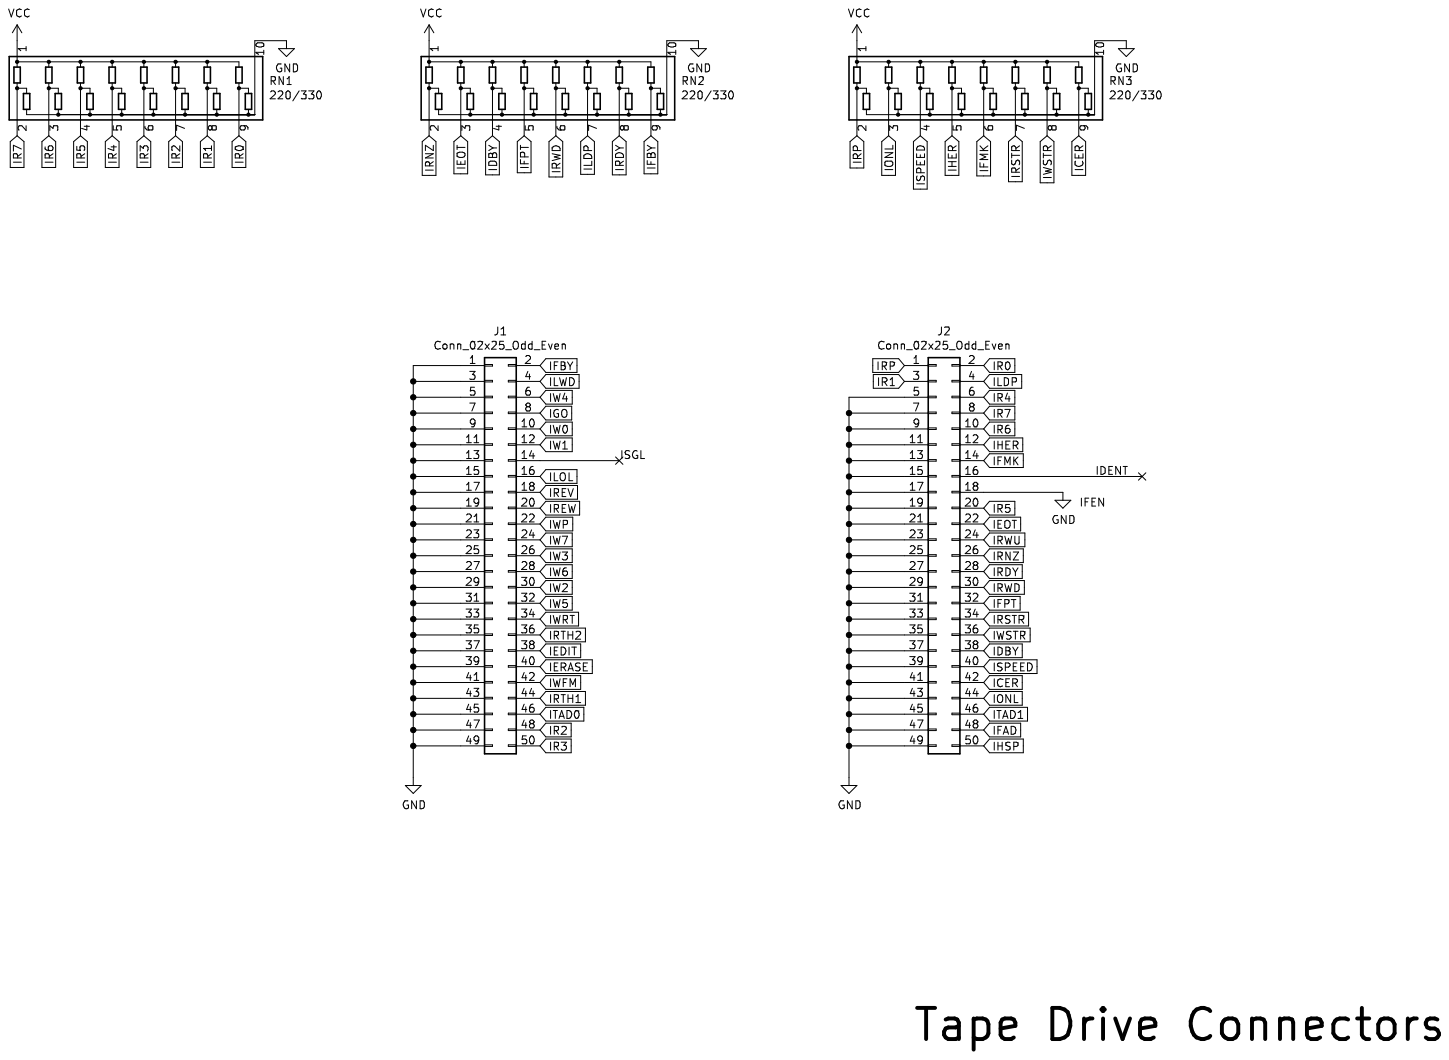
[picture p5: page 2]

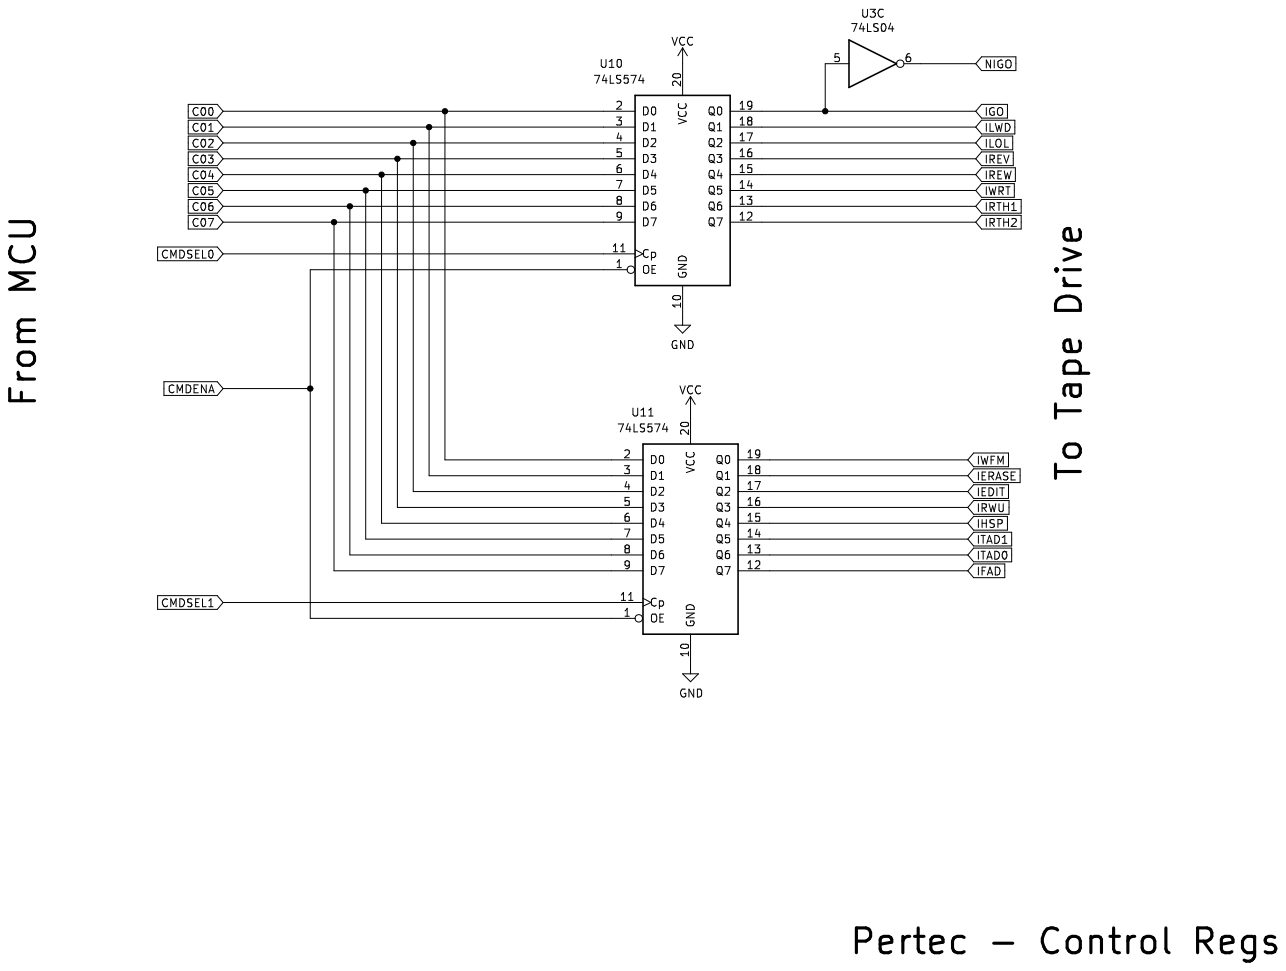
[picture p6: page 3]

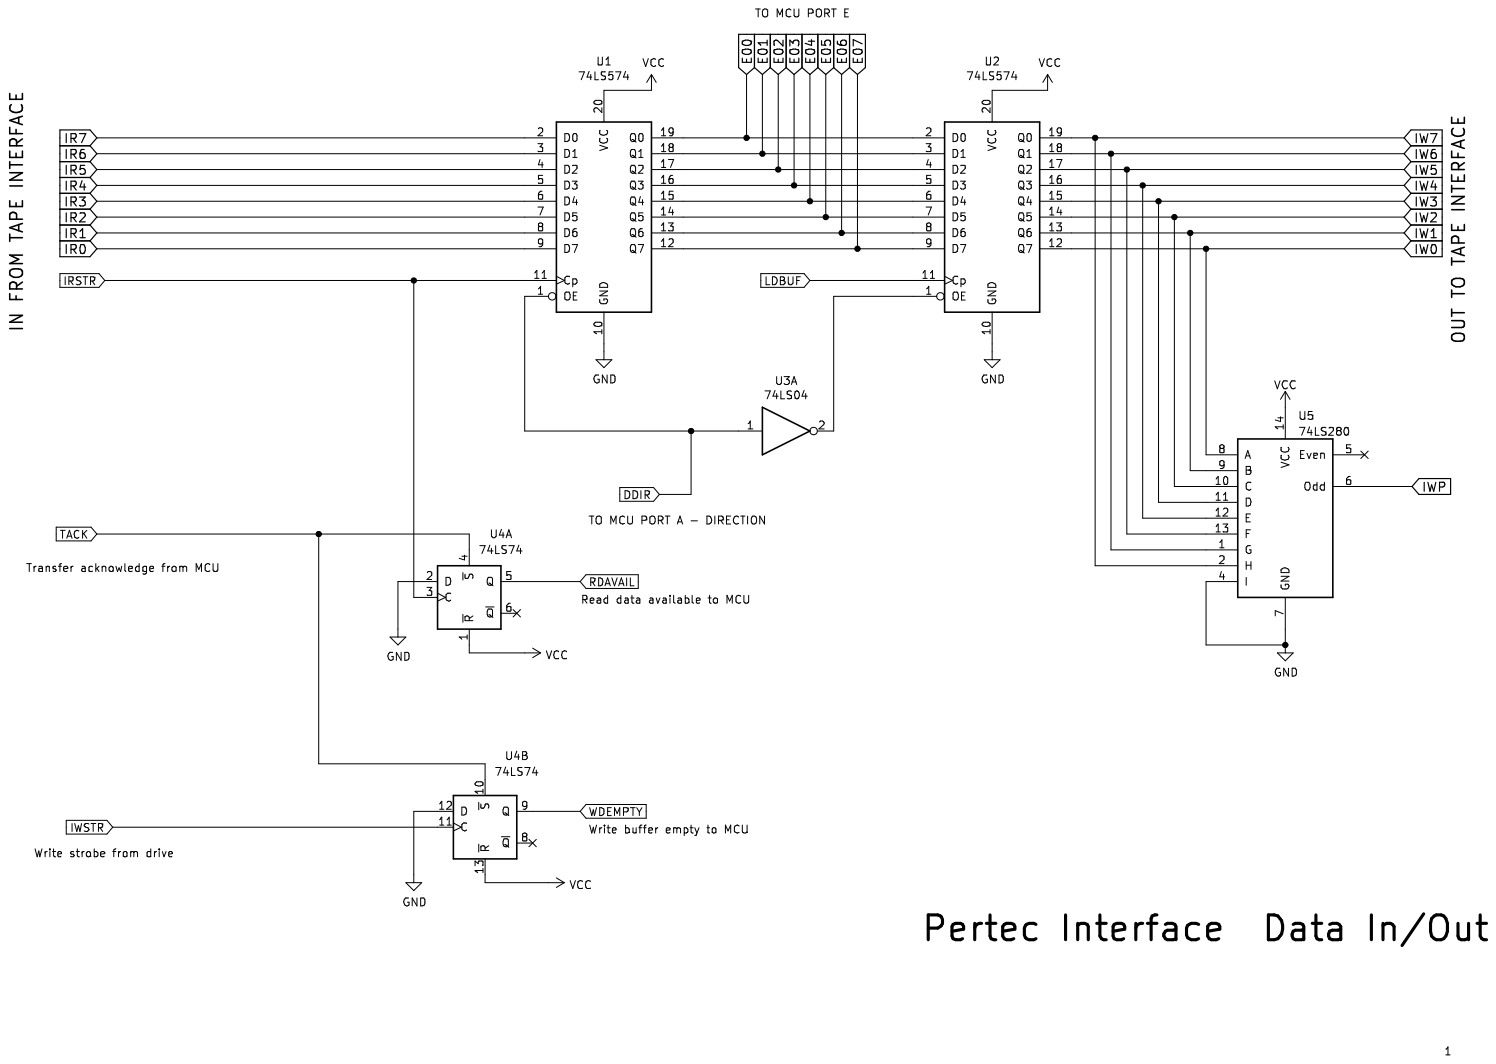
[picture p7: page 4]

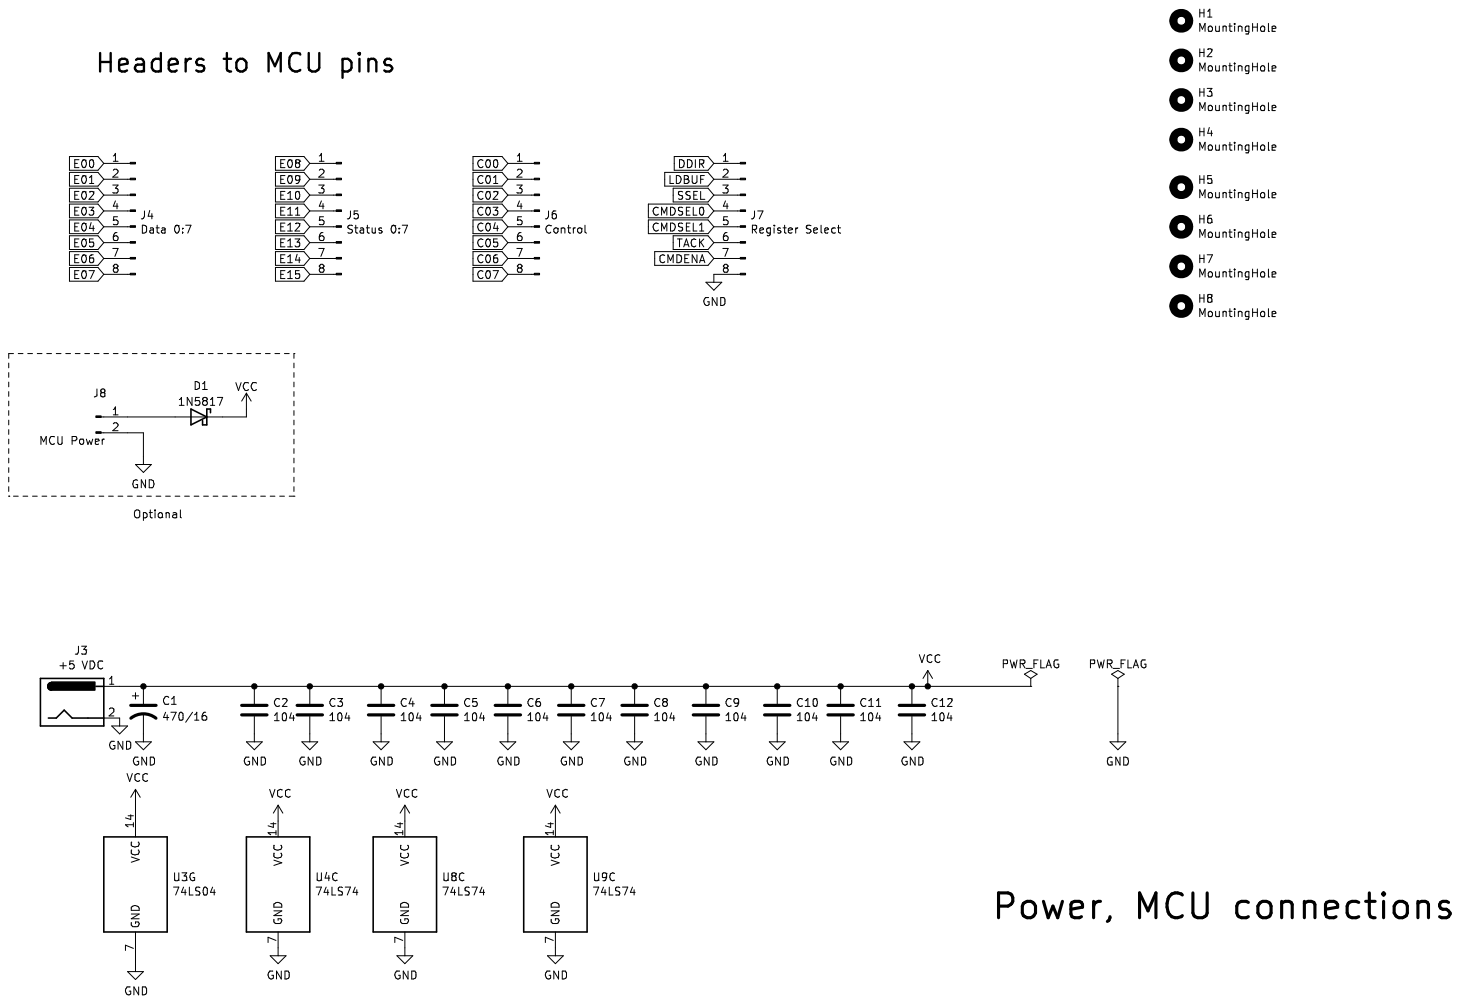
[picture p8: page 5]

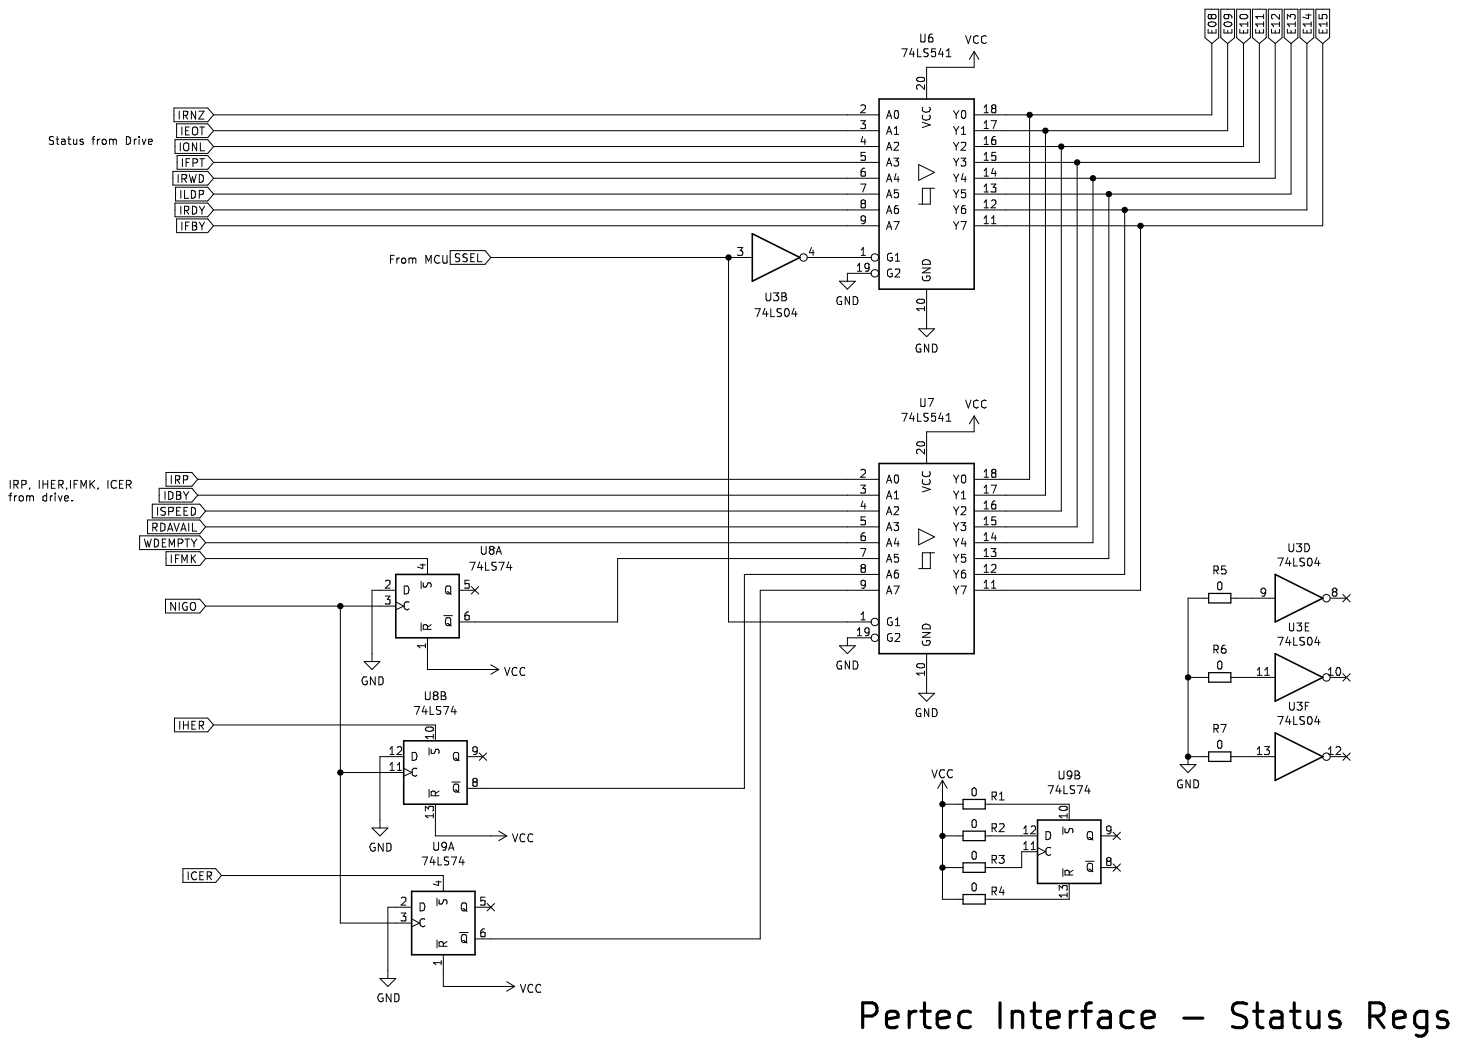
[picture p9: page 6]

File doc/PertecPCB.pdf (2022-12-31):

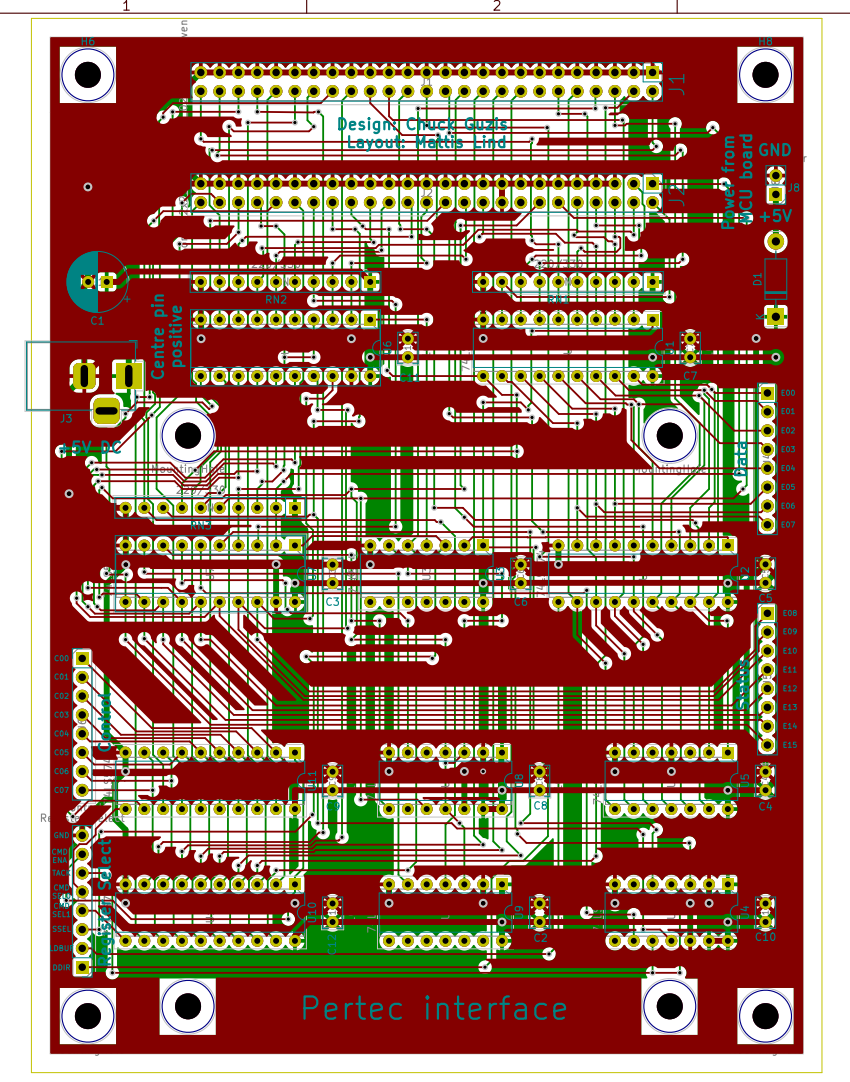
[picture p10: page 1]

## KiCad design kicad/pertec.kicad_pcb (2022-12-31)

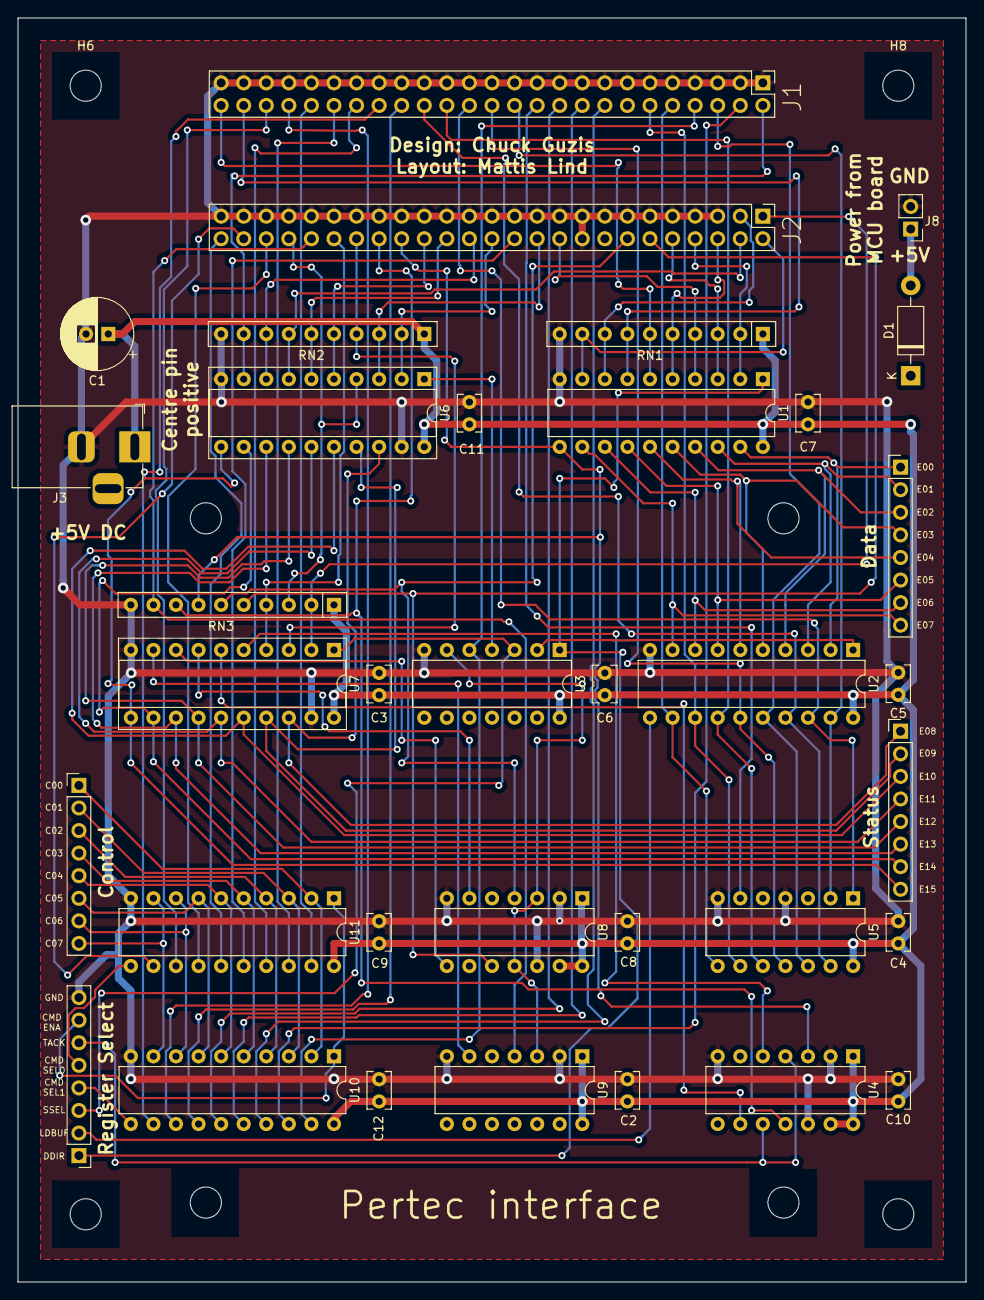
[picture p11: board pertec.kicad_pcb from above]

Board: 2 copper layers, 106.7 x 142.2 mm, 43 parts (0 on the bottom side), 91 nets.

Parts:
C1: 470/16; CP_Radial_D8.0mm_P2.50mm
C2, C3, C4, C5, C6, C7, C8, C9, C10, C11, C12: 104; C_Rect_L4.0mm_W2.5mm_P2.50mm
D1: 1N5817; D_DO-41_SOD81_P10.16mm_Horizontal
H1, H2, H3, H4, H5, H6, H7, H8: MountingHole; MountingHole_3.5mm
J1, J2: Conn_02x25_Odd_Even; PinHeader_2x25_P2.54mm_Vertical
J3: +5 VDC; BarrelJack_Horizontal
J4: Data 0:7; PinHeader_1x08_P2.54mm_Vertical
J5: Status 0:7; PinHeader_1x08_P2.54mm_Vertical
J6: Control; PinHeader_1x08_P2.54mm_Vertical
J7: Register Select; PinHeader_1x08_P2.54mm_Vertical
J8: MCU Power; PinHeader_1x02_P2.54mm_Vertical
RN1, RN2, RN3: 220/330; R_Array_SIP10
U1, U2, U10, U11: 74LS574; DIP-20_W7.62mm
U3: 74LS04; DIP-14_W7.62mm
U4, U8, U9: 74LS74; DIP-14_W7.62mm
U5: 74LS280; DIP-14_W7.62mm
U6, U7: 74LS541; DIP-20_W7.62mm_Socket

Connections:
C00: J6.1, U10.2, U11.2
C01: J6.2, U10.3, U11.3
C02: J6.3, U10.4, U11.4
C03: J6.4, U10.5, U11.5
C04: J6.5, U10.6, U11.6
C05: J6.6, U10.7, U11.7
C06: J6.7, U10.8, U11.8
C07: J6.8, U10.9, U11.9
CMDENA: J7.7, U10.1, U11.1
CMDSEL0: J7.4, U10.11
CMDSEL1: J7.5, U11.11
DDIR: J7.1, U1.1, U3.1
E00: J4.1, U1.19, U2.2
E01: J4.2, U1.18, U2.3
E02: J4.3, U1.17, U2.4
E03: J4.4, U1.16, U2.5
E04: J4.5, U1.15, U2.6
E05: J4.6, U1.14, U2.7
E06: J4.7, U1.13, U2.8
E07: J4.8, U1.12, U2.9
E08: J5.1, U6.18, U7.18
E09: J5.2, U6.17, U7.17
E10: J5.3, U6.16, U7.16
E11: J5.4, U6.15, U7.15
E12: J5.5, U6.14, U7.14
E13: J5.6, U6.13, U7.13
E14: J5.7, U6.12, U7.12
E15: J5.8, U6.11, U7.11
GND: C1.2, C2.2, C3.2, C4.2, C5.2, C6.2, C7.2, C8.2, C9.2, C10.2, C11.2, C12.2, J1.1, J1.3, J1.5, J1.7, J1.9, J1.11, J1.13, J1.15, J1.17, J1.19, J1.21, J1.23, J1.25, J1.27, J1.29, J1.31, J1.33, J1.35, J1.37, J1.39, J1.41, J1.43, J1.45, J1.47, J1.49, J2.5, J2.7, J2.9, J2.11, J2.13, J2.15, J2.17, J2.18, J2.19, J2.21, J2.23, J2.25, J2.27, J2.29, J2.31, J2.33, J2.35, J2.37, J2.39, J2.41, J2.43, J2.45, J2.47, J2.49, J3.2, J7.8, J8.2, RN1.10, RN2.10, RN3.10, U1.10, U2.10, U3.7, U4.2, U4.7, U4.12, U5.4, U5.7, U6.10, U6.19, U7.10, U7.19, U8.2, U8.7, U8.12, U9.2, U9.7, U10.10, U11.10
ICER: J2.42, RN3.9, U9.4
IDBY: J2.38, RN2.4, U7.3
IEDIT: J1.38, U11.17
IEOT: J2.22, RN2.3, U6.3
IERASE: J1.40, U11.18
IFAD: J2.48, U11.12
IFBY: J1.2, RN2.9, U6.9
IFMK: J2.14, RN3.6, U8.4
IFPT: J2.32, RN2.5, U6.5
IGO: J1.8, U3.5, U10.19
IHER: J2.12, RN3.5, U8.10
IHSP: J2.50, U11.15
ILDP: J2.4, RN2.7, U6.7
ILOL: J1.16, U10.17
ILWD: J1.4, U10.18
IONL: J2.44, RN3.3, U6.4
IR0: J2.2, RN1.9, U1.9
IR1: J2.3, RN1.8, U1.8
IR2: J1.48, RN1.7, U1.7
IR3: J1.50, RN1.6, U1.6
IR4: J2.6, RN1.5, U1.5
IR5: J2.20, RN1.4, U1.4
IR6: J2.10, RN1.3, U1.3
IR7: J2.8, RN1.2, U1.2
IRDY: J2.28, RN2.8, U6.8
IREV: J1.18, U10.16
IREW: J1.20, U10.15
IRNZ: J2.26, RN2.2, U6.2
IRP: J2.1, RN3.2, U7.2
IRSTR: J2.34, RN3.7, U1.11, U4.3
IRTH1: J1.44, U10.13
IRTH2: J1.36, U10.12
IRWD: J2.30, RN2.6, U6.6
IRWU: J2.24, U11.16
ISPEED: J2.40, RN3.4, U7.4
ITAD0: J1.46, U11.13
ITAD1: J2.46, U11.14
IW0: J1.10, U2.12, U5.8
IW1: J1.12, U2.13, U5.9
IW2: J1.30, U2.14, U5.10
IW3: J1.26, U2.15, U5.11
IW4: J1.6, U2.16, U5.12
IW5: J1.32, U2.17, U5.13
IW6: J1.28, U2.18, U5.1
IW7: J1.24, U2.19, U5.2
IWFM: J1.42, U11.19
IWP: J1.22, U5.6
IWRT: J1.34, U10.14
IWSTR: J2.36, RN3.8, U4.11
LDBUF: J7.2, U2.11
NIGO: U3.6, U8.3, U8.11, U9.3
unnamed: D1.2, J8.1
unnamed: U2.1, U3.2
unnamed: U3.4, U6.1
unnamed: U7.7, U8.6
unnamed: U7.8, U8.8
unnamed: U7.9, U9.6
RDAVAIL: U4.5, U7.5
SSEL: J7.3, U3.3, U7.1
TACK: J7.6, U4.4, U4.10
VCC: C1.1, C2.1, C3.1, C4.1, C5.1, C6.1, C7.1, C8.1, C9.1, C10.1, C11.1, C12.1, D1.1, J3.1, RN1.1, RN2.1, RN3.1, U1.20, U2.20, U3.14, U4.1, U4.13, U4.14, U5.14, U6.20, U7.20, U8.1, U8.13, U8.14, U9.1, U9.14, U10.20, U11.20
WDEMPTY: U4.9, U7.6

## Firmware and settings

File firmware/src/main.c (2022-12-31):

#define MAIN 1

#include <stdbool.h>
#include <stdlib.h>
#include <string.h>
#include <stdarg.h>
#include <ctype.h>
#include <libopencm3/stm32/rcc.h>
#include <libopencm3/stm32/gpio.h>

#include "license.h"

#include "comm.h"
#include "rtcsubs.h"
#include "gpiodef.h"
#include "globals.h"
#include "sdiosubs.h"
#include "miscsubs.h"
#include "filesub.h"
#include "cli.h"
#include "tapedriver.h"
#include "filedef.h"
#include "dbserial.h"

// Private function prototypes

static void Init( void);


//  Main program entry.
//  -------------------
//
//  Perform initialiation (see "Init" routine)
//  then exit to command processor.
//

int main(void) 
{

  Init();             // go do some initialization

//   Uprintf( "Delay is %d\n",rcc_apb1_frequency / 4000000 - 1);

  ProcessCommand();                     // never comes back
  return 0; 
} // main


//* Initialization tasks.
//  ---------------------
//
//	Sets things up:
//
//	  1)  GPIO configuration
//	  2)  USB ACM (or UART) configuration
//	  3)  Millisecond tick interrupt
//	  4)  Microsecond delay timer
//	  5)  Time of day clock
//	  6)  SD card interface
//	  7)  Tape interface
//
//	  8)  If SERIAL_DEBUG is defined, initialize UART1
//
//  

static void Init( void) 
{

//  Set system clock.
  
 rcc_clock_setup_pll(&rcc_hse_8mhz_3v3[RCC_CLOCK_3V3_168MHZ]);

//  Set up the Systick timer for 1 msec tick.

  Milliseconds = 0;                     // start off ticker
  InitGPIO();				// set up primary GPIOs
  InitACM(115200);			// initialize USB comm
  SetupSysTick();			// get the milliscond timer going
  DelaySetup();				// set up delay timer
  
//  Wait for console check-in.  

  Ugets( (char *) Buffer, 256);         // just clear out any input garbage

  while(1)
  {
    char c;

    Uprintf( "\nPress \'G\' start\n");
 
    c =  Ugetchar();
    if ( c == 'g' || c == 'G')
      break;
  } // wait for a go
    
  Uprintf("\nTape Utility version " VERSION " ready...\n");

//  Get the real-time clock going.

  InitializeRTC();

  Uprintf( "\nRTC initialized.\n");

//  Get SDIO going.

  SD_Init();				// initialize SDcard.
  MountSD( 0);				// do it twice
  
  Uprintf( "\nSDIO initialized.\n");
  
//  Initialize the tape interface.

  TapeInit();  
  
  Uprintf( "\nTape I/O initialized.\n"); 

//  Initialize the UART if serial debugging..

#ifdef SERIAL_DEBUG
  DBinit();		// initialize debug output
  DBprintf( "\nDebug I/O ready.\n");
#endif

  return;
      
} // Init

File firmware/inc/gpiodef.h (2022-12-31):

// GPIO mode definitions.

#define _OUT_PULLUP_SET GPIO_MODE_OUTPUT,GPIO_PUPD_PULLUP,1
#define _OUT_PULLUP_CLR GPIO_MODE_OUTPUT,GPIO_PUPD_PULLUP,0
#define _IN_PULLUP     GPIO_MODE_INPUT,GPIO_PUPD_PULLUP,-1
#define _IN_NONE       GPIO_MODE_INPUT,GPIO_PUPD_NONE,-1
#define _AF_NONE       GPIO_MODE_AF,GPIO_PUPD_NONE,-1
#define _AF_PULLUP     GPIO_MODE_AF,GPIO_PUPD_PULLUP,-1

//  LED definitions.

#define LED1_GPIO      GPIOA    // LED 1 control
#define LED1_BIT       GPIO6
#define LED1_INIT      _OUT_PULLUP_SET

#define LED2_GPIO      GPIOA    // LED 2 control
#define LED2_BIT       GPIO7
#define LED2_INIT      _OUT_PULLUP_SET

#define LED_GPIO      GPIOA     // for the group of LEDs
#define LED_BIT       (LED1_BIT | LED2_BIT)
#define LED_INIT      _OUT_PULLUP_SET

//  USART definitions.

#define USART_RX_GPIO   GPIOA   // USART receive
#define USART_RX_BIT    GPIO10
#define USART_RX_INIT   _AF_NONE

#define USART_TX_GPIO   GPIOA   // USART transmit
#define USART_TX_BIT    GPIO9
#define USART_TX_INIT   _AF_NONE

#define USART_GPIO      GPIOA     // for the group of LEDs
#define USART_BIT       (USART_RX_BIT | USART_TX_BIT)
#define USART_INIT      _AF_NONE

//  SDIO definitions.

#define SDIO_CMD_GPIO   GPIOD     // SDIO command
#define SDIO_CMD_BIT    GPIO2
#define SDIO_CMD_INIT   _AF_PULLUP

#define SDIO_SCK_GPIO   GPIOC     // SDIO clock
#define SDIO_SCK_BIT    GPIO12
#define SDIO_SCK_INIT   _AF_NONE

#define SDIO_D0_GPIO    GPIOC     // SDIO Data 0
#define SDIO_D0_BIT     GPIO8
#define SDIO_D0_INIT    _AF_NONE

#define SDIO_D1_GPIO    GPIOC     // SDIO Data 1
#define SDIO_D1_BIT     GPIO9
#define SDIO_D1_INIT    _AF_NONE

#define SDIO_D2_GPIO    GPIOC     // SDIO Data 2
#define SDIO_D2_BIT     GPIO10
#define SDIO_D2_INIT    _AF_NONE

#define SDIO_D3_GPIO    GPIOC     // SDIO Data 3
#define SDIO_D3_BIT     GPIO11
#define SDIO_D3_INIT    _AF_NONE

#define SDIO_DATA_GPIO  GPIOC     // SDIO Data group
#define SDIO_DATA_BIT   (SDIO_D0_BIT | SDIO_D1_BIT | SDIO_D2_BIT | SDIO_D3_BIT)  
#define SDIO_DATA_INIT  _AF_NONE

//	Definitions for our Pertec interface board.

// Data register--bidirectional; default to input.

#define PDATA_GPIO	GPIOE		// Data register
#define PDATA_BIT	0xff		// 8 bits
#define PDATA_INIT	_IN_NONE	// set to input initially

// Master control register--active low.

#define PCTRL_GPIO	GPIOD		// Pertec control register

#define PCTRL_ENA	GPIO1		// Enable command output
#define PCTRL_DDIR	GPIO5		// Data direction bit	
#define PCTRL_LBUF	GPIO4		// Load buffer bit
#define PCTRL_SSEL	GPIO3		// Status register select (GPIO2 is
                                        // used by SDIO
#define PCTRL_CSEL0	GPIO7		// Select command register 0
#define PCTRL_CSEL1	GPIO6		// Select command register 1
#define PCTRL_TACK	GPIO0		// Transfer acknowledge

#define PCTRL_BIT (PCTRL_DDIR | PCTRL_LBUF | \
        PCTRL_SSEL | PCTRL_CSEL0 | PCTRL_CSEL1 | PCTRL_TACK | PCTRL_ENA)
#define PCTRL_INIT _OUT_PULLUP_SET	// always output, initially high

// Command register - 2 sets

#define PCMD_GPIO	GPIOC		// Pertec command register
#define PCMD_BIT	0xff		// 8 bits
#define PCMD_INIT	_OUT_PULLUP_SET	// see definitions below

// Status registers - 2 sets

#define PSTAT_GPIO	GPIOE		// Pertec status register  
#define PSTAT_BIT	0xff00		// 8 bits (high order)
#define PSTAT_INIT	_IN_NONE	// always input

//  Initialization macros.

#define GPIO_INIT(x) SetupGPIO( x##_GPIO, x##_BIT, x##_INIT)

//  Pin manipulation macros.

#define G_CLEAR(x) gpio_clear( x##_GPIO, x##_BIT)
#define G_SET(x) gpio_set( x##_GPIO, x##_BIT)
#define G_TOGGLE(x) gpio_toggle( x##_GPIO, x##_BIT)
#define G_GETPIN(x) gpio_get( x##_GPIO, x##_BIT)

//  Input-output mode change.

#define G_INPUT(x) gpio_mode_setup(x##_GPIO, GPIO_MODE_INPUT, GPIO_PUPD_NONE, x##_BIT)
#define G_OUTPUT(x) gpio_mode_setup(x##_GPIO, GPIO_MODE_OUTPUT, GPIO_PUPD_PULLUP, x##_BIT)                   

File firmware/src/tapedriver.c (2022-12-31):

//*	Pertec interface low-level routines.
//	------------------------------------

#include <stdint.h>
#include <stdbool.h>
#include <stdlib.h>
#include <ctype.h>
#include <string.h>

// MCU-specific definitions.

#include <libopencm3/stm32/rcc.h>
#include <libopencm3/stm32/gpio.h>
#include <libopencm3/cm3/systick.h>
#include <libopencm3/cm3/nvic.h>
#include <libopencm3/stm32/timer.h>

#include "license.h"

// Local definitions.

#include "comm.h"
#include "gpiodef.h"
#include "miscsubs.h"
#include "globals.h"
#include "tapedriver.h"
#include "pertbits.h"
#include "filedef.h"

//  Static variables used here.

uint16_t
  LastCommand;			// last written contents of command register.

//  Prototypes.

static unsigned int TapeMotion( uint16_t Command);
static void AckTapeTransfer( void);

//	TapeStatus - Read 16 bit status.
//	--------------------------------
//
//	Status 1 in bits 15-8
//	Status 0 in bits 7-0
//
//	Returns the positive tape status;
//

uint16_t TapeStatus( void)
{

  uint16_t res;		// result
  uint8_t ss0, ss1;

//  Do things twice here to delay a bit.

  gpio_clear( PCTRL_GPIO, PCTRL_SSEL);
  gpio_clear( PCTRL_GPIO, PCTRL_SSEL);
  ss0 = (gpio_port_read( PSTAT_GPIO) >> 8);
  ss0 = (gpio_port_read( PSTAT_GPIO) >> 8);
  gpio_set( PCTRL_GPIO, PCTRL_SSEL); 
  gpio_set( PCTRL_GPIO, PCTRL_SSEL); 
  ss1 = (gpio_port_read( PSTAT_GPIO) >> 8);
  ss1 = (gpio_port_read( PSTAT_GPIO) >> 8);

  res = ss0 | (ss1 << 8);
   
  return res ^ 0xffff;
} // TapeStatus

//	Initialzie tape interface.
//	---------------------------
//

void TapeInit( void)
{

// issue a transfer acknowledge

  gpio_clear( PCTRL_GPIO, PCTRL_TACK);
  Delay(1);
  gpio_set( PCTRL_GPIO, PCTRL_TACK);            // ack the transfer
  TapeAddress = 0;				// default address
  StopTapemarks = 2;				// default tape mark stop
  StopAfterError = false;			// if stop after error
  
//  Set the command bits high.

  gpio_set( PCMD_GPIO, PCMD_BIT);	// set all bits to one
  gpio_clear( PCTRL_GPIO, PCTRL_CSEL0);
  Delay(1);
  gpio_set( PCTRL_GPIO, PCTRL_CSEL0);	// latch it in
  Delay(1);  
  gpio_clear( PCTRL_GPIO, PCTRL_CSEL1);
  Delay(1);
  gpio_set( PCTRL_GPIO, PCTRL_CSEL1);	// latch it in
  LastCommand = 0;			// remember this

//  Now enable the command output.

  gpio_clear( PCTRL_GPIO, PCTRL_ENA);	// and there we go...

} // TapeInit

//*	Rewind and Unload - No data phase.
//	==================================

//	TapeRewind - Rewind tape.
//	------------------------
//

unsigned int TapeRewind( void)
{

  uint16_t
    stat;

  
  if (!IsTapeOnline())
    return TSTAT_OFFLINE;		// not online

  stat = TapeStatus();		// See what gives
  if ( stat & PS1_ILDP)
    return TSTAT_NOERR;			// already at loadpoint

//	Issue rewind command.

  IssueTapeCommand( PC_IREW);		// assert rewind
  IssueTapeCommand( 0);			// null commnad
  
  while( TapeStatus() & PS1_IRWD);	// let tape rewind
  return TSTAT_NOERR;
} // TapeRewind

//*	TapeUnload - Unload tape.
//	--------------------------
//

unsigned int TapeUnload( void)
{
  
  if (!IsTapeOnline())
    return TSTAT_OFFLINE;		// not online

//	Issue rewind command.

  IssueTapeCommand( PC_IRWU);		// assert rewind
  IssueTapeCommand( 0);			// null commnad
  
  return TSTAT_NOERR;
} // TapeUnload

//**	Motion functions--no data transfer.
//	===================================


static unsigned int TapeMotion( uint16_t Command)
{

  unsigned int
    retStatus;
  uint16_t  
    status;

  if ( !IsTapeOnline())
    return TSTAT_OFFLINE;	// return if offline

  IssueTapeCommand( PC_IGO | Command);	// assert go+command
  Delay(2);
  IssueTapeCommand( Command);		// release it

//  Wait for IFBY to go active, then active IDBY.

  while( true)
  {
    status = TapeStatus();
    if ( status & PS1_IFBY)
      break;
  }  // wait for formatter busy

//	Okay, we have the formatter acknowledging the command, now wait
//	for the data phase.  If formatter busy drope while waiting, we
//	bombed.
  
  do
  {
    status = TapeStatus();
    if ( !(status & PS1_IFBY))
    {
      return TSTAT_OFFLINE;		// tape dropped ready
    }

  } while( (status & PS0_IDBY) == 0);	// wait for data phase

//	Kill time while data busy is set.  

  do
  {
    status = TapeStatus();
  } while ( status & PS0_IDBY);

//	Wait for formatter busy to drop.

  do
  {
    status = TapeStatus();
  } while ( status & PS1_IFBY);

  retStatus = TSTAT_NOERR;

  if ( (status & PS0_IFMK))
    retStatus |= TSTAT_TAPEMARK;		// say we have a tapemark

  if ( (status & PS0_IHER))
    retStatus |= TSTAT_HARDERR;		// signal hard error
  
  if ( status & PS1_EOT)
    retStatus |= TSTAT_EOT;		// say end of tape
    
  return retStatus;			// all done  
} // TapeMotion

//*	SkipBlock - Skip one block forward or backward.
//	-----------------------------------------------
//
//	Sign of argument determines direction.
//
//	Returns the usual TSTAT status
//

unsigned int SkipBlock( int Dir)
{

  unsigned int
    status;
  uint16_t  			// tape status
    tCommand;			// command we're sending

  tCommand = PC_IERASE;
  if ( Dir < 0)
    tCommand |= PC_IREV;
    
  status = TapeMotion( tCommand);	// issue it
  return status;			// all done--successful
} // SkipBlock


//*	SpaceFile - Space filemarks forware or backward.
//	------------------------------------------------
//
//	The argument is + for forward, - for backward.
//

unsigned int SpaceFile( int Dir)
{

  unsigned int
    status;

  uint16_t
    tCommand;			// command we're sending

  tCommand = PC_IWFM;		// space with data
  if ( Dir < 0)
    tCommand |= PC_IREV;
    
  status = TapeMotion( tCommand);	// issue it
  return status;			// all done
} // SpaceFile

//*	Read/Write Functions.
//	=====================


//*	TapeRead - Read a tape block.
//	-----------------------------
//
//	Reads (forward) a block from a tape into a buffer.
//	Returns the size of the block read and the status.
//
//	Status can be a combination of any of these:
//		TSTAT_OFFLINE 	- Drive is offline
//		TSTAT_HARDERR 	- Formatter detected a hard error
//		TSTAT_CORRERR 	- Formatter corrected an error
//		TSTAT_TAPEMARK 	- Record is a tape mark
//		TSTAT_EOT	- End of tape encountered
//		TSTAT_BLANK	- Blank tape read
//		TSTAT_LENGTH	- Block longer than buffer
//		TSTAT_NOERR	- No error detected
//
//	Some conditions such as read past EOT, offline, blank or tapemark
//	return a data count of zero.
//
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
